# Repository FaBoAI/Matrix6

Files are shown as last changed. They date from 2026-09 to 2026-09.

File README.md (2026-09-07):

# Matrix Six

ESP32-S3-WROOM-1-N8R8を使った、Matrix5シールド向けのKiCad 10開発基板です。現行設計は **v0.8（2層・四隅R2 mm）**。内層配線を表裏へ移し、USBとGNDを再設計しました。オートルーターは使わず、部品配置と配線を個別に指定しています。

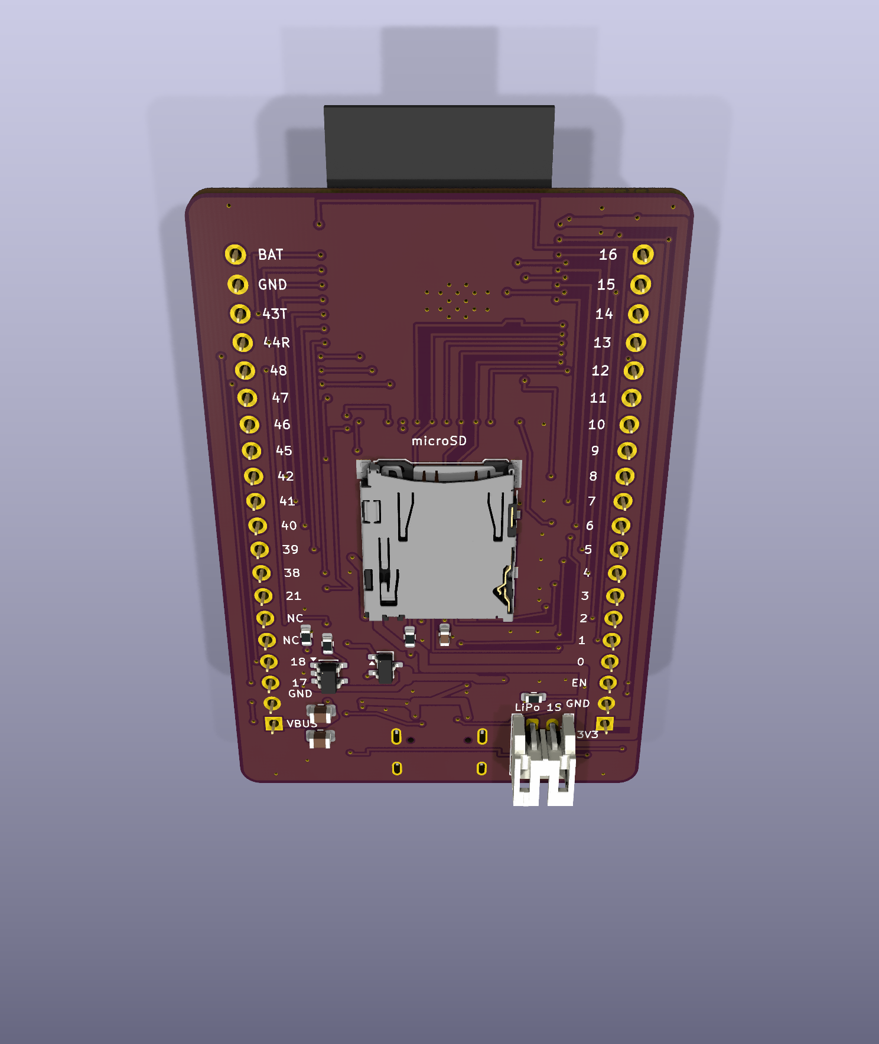
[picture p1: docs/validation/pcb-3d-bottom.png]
Matrix Six裏面3D・30度


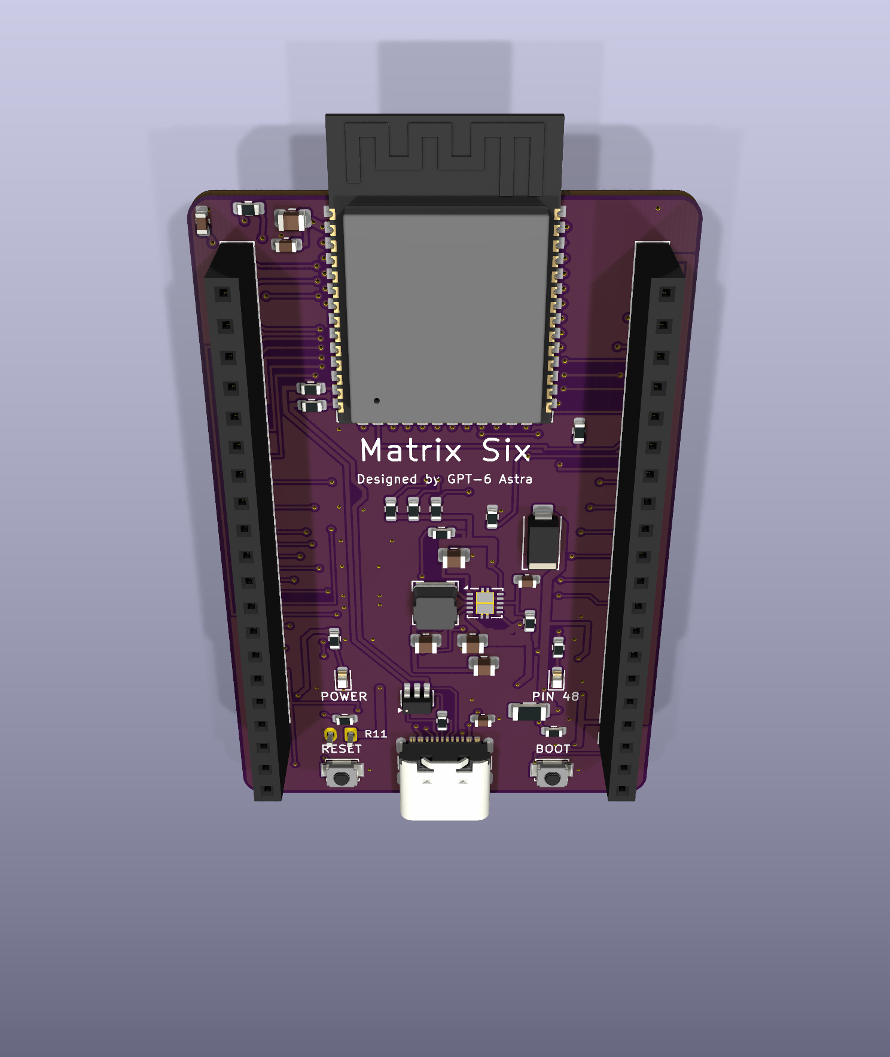
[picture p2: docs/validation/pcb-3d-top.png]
Matrix Six表面3D・30度


## KiCadで開く

[Matrix6.kicad_pro](hardware/Matrix6/Matrix6.kicad_pro)をKiCad 10で開いてください。KiCad標準のシンボル・フットプリント・3Dモデルライブラリをインストールし、同じフォルダーの `DevBoard.pretty` と `fp-lib-table` を一緒に保管します。動作確認版はKiCad 10.0.6です。

- ESP32-S3-WROOM-1-N8R8、ネイティブUSB-C、TPS63001によるUSB／LiPo両対応3.3 V電源。
- 裏面microSD（CS=10、MOSI=11、CLK=12、MISO=13）。口はアンテナ側へ向け、15.8 × 22.5 mmの抜き差し空間を確保。
- 裏面JST-PH 2ピンLiPo端子、MCP73831で公称100 mA充電、AO3401AによるUSB／電池自動切替。
- USBの左にRESET、右にBOOT。基板下部の赤LEDは `POWER`、青LEDはGPIO48の `PIN 48`。
- 40.64 × 61.00 mm、四隅R2 mm、2層FR4・公称1.6 mm・両面1 oz。USBは表面のみ・ビア0。表面のUSB両脇にGNDを確保し、表裏のGNDベタをビアで接続。
- H1/H2は各20ピン、ピッチ2.54 mm、列間33.02 mmのメスソケット。1番ピンはUSB側。
- 表面中央に大きな `Matrix Six`（文字高2.0 mm）、その直下に `Designed by GPT-6 Astra`（0.8 mm）。

## Matrix5シールドとの互換性

[Matrix5](https://github.com/FaBoAI/Matrix5)のMainとS1〜S11の実設計から端子情報を読み取り、全40位置と各シールドの使用信号を照合しました。**38端子の割り当てを合わせ、H2.20はVBAT**です。H2.5 / H2.6はNC（Matrix5のUSB D− / D＋）で、確認した11シールドはいずれも使用していません。

[端子表・シールド別照合・取り付け条件](docs/matrix5-compatibility.md)を参照してください。XY位置と使用ピンは一致していますが、積層高さ、アンテナ周辺、通電動作は実機での確認が必要です。USB-UART機能は追加していません。SDはシールドのSPI/I2C用GPIO11〜13を共有するため、競合する使い方ではカードを抜いてください。

電源計算の条件は周囲50℃、**3.3 V合計500 mA（MCU・SDを含む）＋VBUSシールド負荷100 mA＋充電100 mA**です。H1.1/H2.1は出力専用で、H2.1へ外部給電するとUSBへ逆給電できます。大電流のLED全点灯・コイル・ヒーターはこの条件に含みません。GPIOは3.3 Vで、S1用5 Vレベル変換はありません。

LiPoは保護回路付き1セル3.7 V／満充電4.2 V、500 mAh以上・放電定格1 A以上を基準とします。J3は**1番BAT+、2番GND**。同じJST形状でも電池側の極性を確認してください。電池動作中のH2.1に5 Vは出ません。セル温度センサーは搭載していません。

## 検証と図面

| 項目 | 保存したv0.8の結果 |
|---|---|
| DRC / ERC / 未配線 / 回路図整合性 | すべて0件 |
| 外形 | 四隅R2 mm、直線4本＋円弧4本で閉じた輪郭 |
| SD抜き差し空間 | 裏面15.8 × 22.5 mm、部品の配置禁止領域。重なり0 |
| Matrix5端子照合 | 全11シールドの使用ピン・40位置が一致 |
| USB | 表面のみ・ビア0、A/B両側とも幾何学的な長さ差0.01 mm未満 |
| USB本体下 | 表面配線・ビア・ベタ0。禁止領域の負の試験でも検出を確認 |
| USB直線部の表面GND | 両脇の幅0.5 mmを各1,563点検査、欠損0 |
| 電源降下の計算 | 3.3 V・500 mAでモジュールまで49.9 mV、H1まで27.9 mV |
| GND帰路のDC計算 | モジュール帰路500 mAで2.34 mV、入力帰路800 mAで6.45 mV |
| 最小ドリル | 0.3 mm。U1放熱穴はパッド0.8 mm、環状幅0.25 mm |

- [回路図](docs/validation/schematic.png) / [表面配線](docs/validation/pcb-top.png) / [裏面配線](docs/validation/pcb-bottom.png) / [SD抜き差し図](docs/validation/sd-access.svg)
- [DRC](docs/validation/drc.json) / [ERC](docs/validation/erc.json) / [シールド照合](docs/validation/matrix5-compatibility.json)
- [USB禁止領域](docs/validation/usb-keepout-validation.json) / [配線・電源計算](docs/validation/electrical-audit.json) / [GND計算](docs/validation/ground-plane-dc.json)
- [2層化の設計・検証範囲](docs/matrix-six-v08.md) / [USB断面計算](docs/analysis/two-layer-usb.json) / [表面GND検査](docs/validation/two-layer-ground.json)
- [検証対象CADのSHA-256](docs/validation/cad-sha256.json) / [回路図と30°3Dの並列表示](docs/validation/schematic-and-3d.png)

USBの均一断面は幅0.38 mm・線間0.18 mm・表面GNDとの間隔0.20 mm。FR4のεr=4.5を仮定した2D計算は約90.3 Ωです。裏面GNDは信号配線で4領域に分かれ、表面とビアで接続されており、連続した裏面参照プレーンではありません。USBの主な帰路は表面の両脇GNDとして設計しています。A側の長さにはR11のパッド間1.65 mmを含みます。

JLCPCB標準2層での管理インピーダンス保証は前提にしていません。断面・DC・配線温度の結果は設計計算であり、局所的な曲がりや長さ調整、コネクタを含むUSBの実測保証ではありません。試作機でUSB両挿し向き、SI/EMC、SD同時動作、給電切替・負荷・温度を確認します。

## JLCPCBへの試作発注

[v0.8の2層版製造データ](manufacturing/v0.8/README.md)を使用してください。48部品・26 BOMグループの型番は継承していますが、部品移動と表裏変更があるため **CPLもv0.8へ差し替えが必要**です。U1/U2等の放熱・パッド内ビアには充填と銅キャップを要求しており、両面実装費も残ります。最終削減額は新しい見積もりで確認してください。

既存のv0.7注文は4層版のデータです。v0.8の製造データとの混用はできません。部品在庫、実装位置・極性、CAMの確認が必要で、この作業では支払い・製造承認は行っていません。

JLCPCBに見積時点のGerberをアップロードし、基板5枚のWeb表示額は **$83.27**（部品・実装・送料別）でした。旧4層注文の$120.47から約31%減ですが、条件を最適化した4層比較額$86.68との差は約4%です。[見積もり内訳と条件](docs/analysis/two-layer-v08-quote.md)

## 検証の再実行

```sh
python3 scripts/verify_project.py
```

リポジトリをgit cloneして実行してください。設計ルール・互換性・外形の比較にはgit履歴が必要です。KiCad CLIと `pcbnew` / `wx` を使えるPythonが必要です。macOSの標準KiCadインストールは自動選択します。他の環境では `KICAD_CLI` と `KICAD_PYTHON` を指定してください。`ANALYSIS_PYTHON` にNumPy / SciPy / Shapely / Matplotlibを導入したPythonを指定すると、表裏を接続したGNDのDC計算も再実行します。検証はゾーンを再充填してPCBを保存し、レポートを更新するため、GUI上の編集を先に保存してください。

`scripts/manual_matrix5_layout.py` は初期インポートのコミットを入力とした、座標指定による移行記録です。オートルーターではありません。再実行すると後からのCAD編集を上書きするので、通常の検証には使いません。

v0.6の回路選定・電源条件は [設計メモ](docs/matrix-six-v06.md) に記録しています。

v0.7の外形変更は `scripts/round_board_corners.py`、v0.8の2層化は `scripts/redesign_two_layer.py` と `scripts/two_layer_routes.py` に記録しています。後者は `f12c10f` の4層CADから座標指定の変更を再生し、現在のCADを上書きするため通常の検証には使いません。v0.8の [外形検証](docs/validation/rounded-corners.json) はR2輪郭の保持と0.3 mm最小穴を確認します。版別の製造出力はPCBのリビジョンから出力先を決定します。

旧DevBoardの資料は [docs/devboard-v04](docs/devboard-v04/README.md) に履歴として保存しています。現在の端子・給電条件はこのREADMEとv0.6の互換性資料を使用してください。ライブラリの帰属は [THIRD_PARTY_NOTICES.md](THIRD_PARTY_NOTICES.md) に記載しています。

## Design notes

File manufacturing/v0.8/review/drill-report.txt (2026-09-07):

Drill report for Matrix6.kicad_pcb
Created on 2026-09-08T08:52:20

Copper Layer Stackup:
    =============================================================
    L1 :  F.Cu                      front
    L2 :  B.Cu                      back

Drill file 'Matrix6-PTH.drl' contains
    plated through holes:
    =============================================================
    T1  0.300mm  0.0118"  (166 holes))
    T2  0.300mm  0.0118"  (12 holes))
    T3  0.600mm  0.0236"  (4 holes)  (with 4 slots)
    T4  0.750mm  0.0295"  (2 holes))
    T5  1.000mm  0.0394"  (40 holes))

    Total plated holes count 224

Drill file 'Matrix6-NPTH.drl' contains
    unplated through holes:
    =============================================================
    T1  0.650mm  0.0256"  (2 holes))

    Total unplated holes count 2

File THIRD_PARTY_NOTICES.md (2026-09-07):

# Third-party library data

The KiCad community provides the standard symbols, footprints and 3D model references used by this project. See the [KiCad library license](https://gitlab.com/kicad/libraries/kicad-footprints/-/blob/master/LICENSE.md): CC BY-SA 4.0 with the KiCad electronic-design exception.

The project-local footprint collection in `hardware/Matrix6/DevBoard.pretty` contains modified KiCad library footprints and is distributed under that same library license. A copy of the upstream notice is included as `DevBoard.pretty/LICENSE.md`.

- `ESP32-S3-WROOM-1_Edge` derives from `RF_Module:ESP32-S3-WROOM-1`. The project changes the antenna/board-edge accommodation; standard module pad positions are retained.
- `USB4105_NoUnderbodyCopper` derives from `Connector_USB:USB_C_Receptacle_GCT_USB4105-xx-A_16P_TopMnt_Horizontal`. The project adds the named F.Cu track/via/pour keepout for the connector body; standard connector pad positions are retained.

Matrix5 interface references are derived from the owner's MatrixFive designs and the public [FaBoAI/Matrix5](https://github.com/FaBoAI/Matrix5) project. The raw private EasyEDA project was not included in this repository.

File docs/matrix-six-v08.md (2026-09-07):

# Matrix Six v0.8 — 2層への再設計

2026-09-08。v0.7の4層基板を、F.Cu / B.Cuだけの2層へ再設計した試作版です。内層配線を削除するだけの変換ではなく、信号・電源・USB・GNDを配線し直しました。オートルーターは使用していません。

## 維持した仕様

40.64 × 61 mm・四隅R2 mm、H1/H2の全40位置、Matrix5の38割当端子＋2 NC、全11シールドの使用ピンを維持しています。USBと左右のRESET/BOOT、下部POWER/PIN 48 LED、裏面microSDの15.8 × 22.5 mm抜き差し空間、裏面LiPo端子と100 mA充電・自動切替を維持しました。表面のMatrix Sixは文字高2.0 mmへ拡大し、直下にDesigned by GPT-6 Astra（文字高0.8 mm）を配置しています。両行は基板中心X=117.78 mmに揃え、R8をモジュール右側（X=129.3、Y=120.3 mm、90°）へ移動して文字領域を空けました。IO46の分岐配線を引き直し、GND側は表面ベタに直接接続しています。

部品は48個、BOMは26グループで同じ型番です。配線経路のためR5/C4/C5/R8/R9等を移動し、R6を裏面、C11を表面へ移しました。C11はmicroSD用のバルク容量で、裏面スロット近傍のC12 100 nFは保持しています。現在の座標・面・回転は[v0.8 CPL](../manufacturing/v0.8/assembly/Matrix6-v0.8-CPL.csv)と[実装基準図](../manufacturing/v0.8/review/Matrix6-assembly-reference.png)を正としてください。

## 層構成と穴

| 項目 | v0.8 |
|---|---|
| 銅層 | F.Cu / B.Cuのみ |
| 製造時の指定 | FR4、公称1.6 mm、両面1 oz |
| CAD断面 | 表裏銅箔各0.035 mm、コア1.530 mm、εr=4.5 |
| レジストのモデル | 各0.0127 mm、εr=3.8。CAD全厚はレジスト込み1.6254 mm |
| 通常ビア | 完成穴径0.30 mm、銅箔径0.60 mm |
| U1放熱穴12個 | 完成穴径0.30 mm、銅箔径0.80 mm、環状幅0.25 mm |
| 最小PTH環状幅 | USBの長穴部0.20 mm、検査下限0.18 mm |

U1の旧0.2 mm穴を0.3 mmへ広げ、2層の微細穴料金区分を避ける形状にしました。放熱・パッド内ビアのエポキシ充填と銅キャップは製造要求に残ります。コネクタ挿入穴、USB長穴、NPTHは開口します。充填方式・料金・仕上がりの最終確認はCAMが必要です。

## USBとGND

USBはすべて表面、ビア0。USB本体下の表面配線・ビア・ベタは0です。禁止領域に意図的な違反を置いた一時コピーでも検出を確認しました。

均一断面は **線幅0.38 mm、線間0.18 mm、両脇GNDとの間隔0.20 mm**。直線区間Y=128.5〜141.5 mmで、各側0.5 mm幅のGND帯を各1,563点検査し、欠損0を確認しました。裏面ベタは信号配線で4領域に分かれ、表面とスティッチを通じて導通しています。裏面全体を連続した参照プレーンとは見なしません。

| USB経路 | D− | D＋ | 長さ差 |
|---|---:|---:|---:|
| 直列抵抗〜USB-C A側 | 48.020 mm | 48.020 mm | <0.01 mm |
| 直列抵抗〜USB-C B側 | 46.303 mm | 46.303 mm | <0.01 mm |
| モジュール〜直列抵抗 | 1.714 mm | 1.712 mm | 0.003 mm |

A側D＋にはR11のパッド中心間1.65 mmを幾何学的な長さとして含みます。部品内部の電気的遅延を測定した値ではありません。

[2D奇モード静電界計算](analysis/two-layer-usb.json)では、公称90.22 Ω、細かいメッシュで90.26 Ω。両脇GND幅を検査済みの0.5 mmに限定して90.26 Ω、遠方の裏面参照を除いた場合90.30 Ωでした。線幅±0.02 mm、線間±0.02 mm、GND間隔±0.02 mm、εr±0.2を組み合わせた感度ケースは83.72〜96.91 Ωです。**これらの振れ幅は仮定で、JLCPCBの保証公差ではありません。**

この計算は均一断面に限定され、コネクタ・部品・曲がり・長さ調整部や周波数依存損失を含みません。管理インピーダンス保証、TDR、USB規格適合の代わりにはなりません。JLCPCB標準2層では管理インピーダンスの保証を前提にせず、試作での確認を必要とする設計です。[EspressifのUSB配線要件](https://docs.espressif.com/projects/esp-hardware-design-guidelines/en/latest/esp32s3/pcb-layout-design.html)、[JLCPCBの材料・製造能力](https://jlcpcb.com/capabilities/pcb-capabilities/)

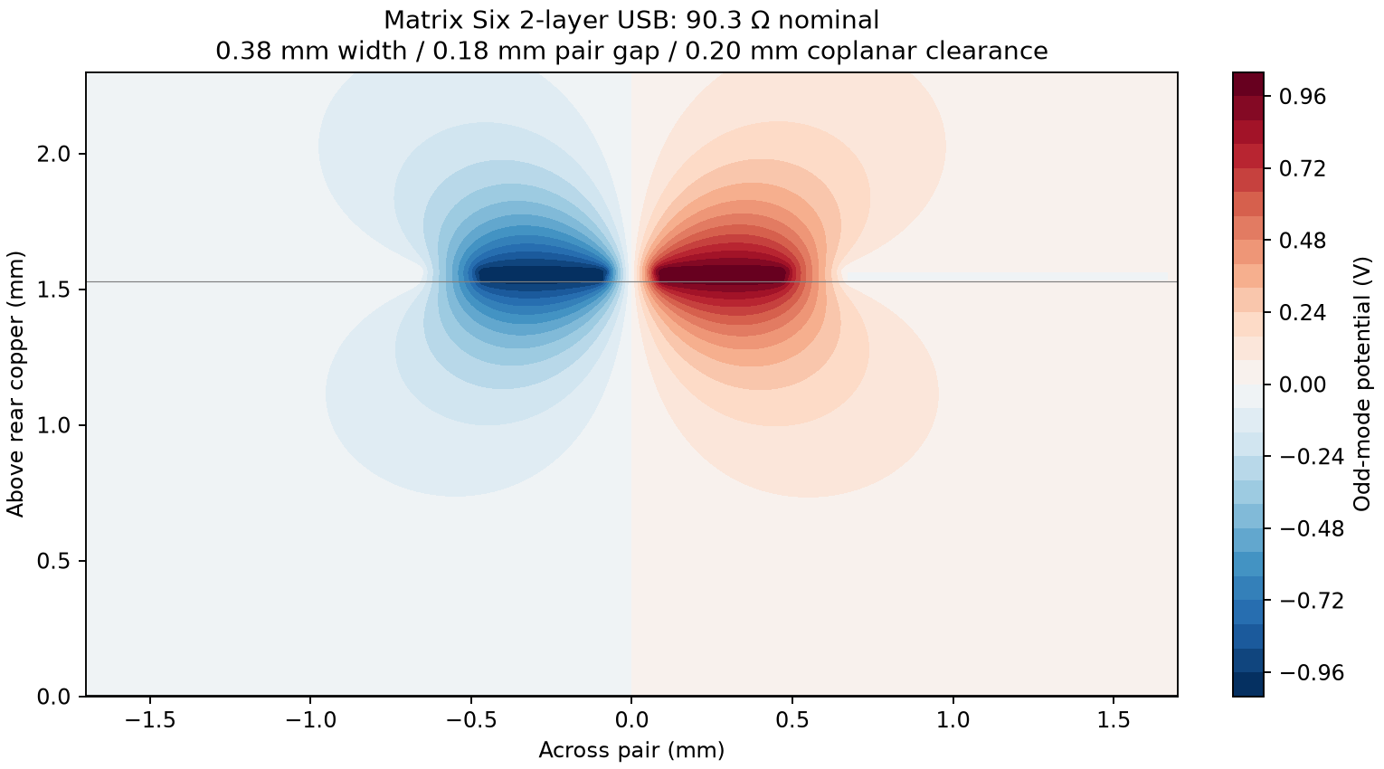
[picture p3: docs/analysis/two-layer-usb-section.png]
USB断面モデル


## 電源・帰路の計算

銅温度60℃、銅厚35 µm、ビアめっき20 µmの仮定です。配線の抵抗は実際の経路から算出しています。負荷条件と電源ICの制限は[README](../README.md)および[v0.6電源設計](matrix-six-v06.md)に従います。

| 経路 | 負荷 | 銅配線の電圧降下 |
|---|---:|---:|
| 3.3 Vコンバーター→ESP32 | 500 mA | 49.9 mV |
| 3.3 Vコンバーター→H1 | 500 mA | 27.9 mV |
| 3.3 Vコンバーター→microSD | 200 mA | 11.0 mV |
| LiPo→切替PFET | 800 mA | 13.2 mV |
| 切替PFET→コンバーター | 800 mA | 12.7 mV |

各行は経路の検討条件で、これらの電流を同時に加算してよい意味ではありません。3.3 VはMCU・SD・シールドを含む合計500 mAを設計条件とします。

表裏の充填済みGND、GNDパッド・配線、穴、64個の層間接続を含めた[DCメッシュ計算](validation/ground-plane-dc.json)では、モジュール帰路500 mAで2.34 mV、入力帰路800 mAで6.45 mVです。前者は0.125→0.0625 mmのメッシュ細分化で1%以内に収束しました。表面GND検査の44個という値は通常のGNDビア数で、DCモデルの64接続はGNDのPTHパッド等も含みます。接触抵抗・はんだ抵抗は含みません。

IPC-2221式による配線温度上昇のスクリーニング値は最大約6.1℃。周囲・銅温度の仮定、熱の拡散、部品自身の損失によって実温度は変わります。IPC-2152評価や熱解析・実測ではありません。

## 検証と製造の状態

- KiCad 10.0.6：全重大度のDRC 0、ERC 0、未配線0、回路図整合性違反0。
- Matrix5の40位置と11シールド、SD抜き差し、USB底面禁止領域、R2外形、最小穴・環状幅を検証。
- GND再充填後の[CADハッシュ](validation/cad-sha256.json)を保存。製造出力時に同一CADか再照合。
- USB両挿し向き・実機通信、SI/EMC、Wi-FiとSDの同時動作、低電池時の電源切替、突入電流・最大負荷・温度は試作で検証する項目。
- v0.7の既存注文は旧4層のまま。v0.8で支払い・製造承認は行っていない。最終的な削減額は2層の再見積もりで確定する。

再現用の座標指定変更は `scripts/redesign_two_layer.py` と `scripts/two_layer_routes.py`。4層版 `f12c10f` を入力として現在のCADを上書きするので、通常は `scripts/verify_project.py` だけを実行してください。

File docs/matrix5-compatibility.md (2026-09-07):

# Matrix5シールド互換性 — Matrix Six v0.6

Matrix5 MainのJ4/J5と同じ順序で、Matrix6のH1/H2を配線しました。ピッチ2.54 mm、各20ピン、列間33.02 mmです。表面から見てH1が左、H2が右、**1番ピンはUSB側**です。旧DevBoard v0.4の30.48 mmヘッダーとは互換ではありません。

照合元は、2026-09-07に読み取り専用APIで取得したEasyEDAの `MatrixFive_Main_PCB` とS1〜S11の実設計です。公開されている製造ZIPの `FlyingProbeTesting.json` でも位置・使用ピンを照合しました。公開側の基準コミットは [Matrix5 4e5bad0](https://github.com/FaBoAI/Matrix5/tree/4e5bad09b81449c644275b11321cdfa5019caf93) です。抽出した[Mainの端子表](reference/matrix5-pinout.json)と[シールドの使用端子](reference/matrix5-shield-interface.json)を保存しています。

## 端子表

| ピン | H1 | H2 |
|---:|---|---|
| 1 | 3V3出力 | VBUS出力（F1保護後） |
| 2 | GND | GND |
| 3 | EN | GPIO17 |
| 4 | GPIO0 / BOOT | GPIO18 |
| 5 | GPIO1 | NC：Matrix5ではUSB D− |
| 6 | GPIO2 | NC：Matrix5ではUSB D＋ |
| 7 | GPIO3 | GPIO21 / S1 DATA |
| 8 | GPIO4 | GPIO38 |
| 9 | GPIO5 | GPIO39 |
| 10 | GPIO6 | GPIO40 |
| 11 | GPIO7 | GPIO41 |
| 12 | GPIO8 | GPIO42 |
| 13 | GPIO9 | GPIO45 |
| 14 | GPIO10 | GPIO46 |
| 15 | GPIO11 / MOSI / SDA | GPIO47 |
| 16 | GPIO12 / SCLK / SCL | GPIO48 / 青LED |
| 17 | GPIO13 / MISO | GPIO44 / RX |
| 18 | GPIO14 / HEAT_EN | GPIO43 / TX |
| 19 | GPIO15 | GND |
| 20 | GPIO16 | VBAT（J3の電池端子） |

**38端子の信号・電源を合わせ、USB D±の2端子は意図的に未接続です。** H2.20をVBATへ接続しました。確認した11シールドの使用端子は一致しています。SDはGPIO10〜13を共有します。GPIO11/12をI2Cとして使うときなど、カードと競合する構成ではカードを抜いてください。

## シールド別の照合範囲

| シールド | 照合した機能 | 使用端子数 |
|---|---|---:|
| S1 WS2812 6×6 | H2.7のGPIO21、VBUS、GND | 5 |
| S2 ICM20948 | GPIO1〜9のCS、SPI、3V3、GND | 16 |
| S3 BME690 | GPIO1〜9のCS、SPI、3V3、GND | 16 |
| S4 MLX90393 | GPIO1〜9のCS、SPI、3V3、GND | 16 |
| S5 VL53L1X | GPIO1〜9のXSHUT、I2C、3V3、GND | 15 |
| S6 BMP581 | GPIO1〜9のCS、SPI、3V3、GND | 16 |
| S7 VL6180X | GPIO1〜9のCE、I2C、3V3、GND | 15 |
| S8 Touch | GPIO1〜9 | 9 |
| S9 MagPix | GPIO1〜9、VBUS、GND | 13 |
| S10 AirFlow | GPIO1〜9、GPIO14、3V3、VBUS、GND | 15 |
| S11 Display | GPIO1〜4、MOSI/SCLK、3V3、VBUS、GND | 11 |

各シールド40か所のパッド座標と上表の使用端子を、保存したKiCad PCBに対して検査しています。[検証結果](validation/matrix5-compatibility.json)はピン配置の一致を示すもので、実物を積層して通電した結果ではありません。S2/S4/S6/S9はMatrix5側の改版履歴にも従ってください。

## 機械寸法と取り付け

Matrix6は40.64 × 61.00 mm。H1.1=(101.27,153.26)、H2.1=(134.29,153.26) mmで、番号が増える方向はKiCad上で−Yです。標準シールド40.64 × 53.34 mmを重ねると、外形はX=97.46〜138.10、Y=102.46〜155.80 mmとなります。USBとRESET/BOOTはその下側に残ります。S11は長い基板のため、外形全体はこの範囲を超えます。

H1/H2は表面の1×20メスソケット用フットプリントです。ソケット・オスピン・スペーサーの組合せは、シールド裏面の部品とMatrix6のESP32モジュール等の高さを実測して決めてください。ヘッダーのXY一致だけで積層高さや筐体への適合は保証できません。アンテナ上を金属や別基板で覆わず、積層した状態の無線性能も確認します。

## 電源・ファームウェアの条件

- I/Oは3.3 V。S1へ出すGPIO21も3.3 Vで、追加の5 Vレベル変換はありません。S1実装LEDの入力閾値と波形を試作で確認してください。
- 3V3の計算条件はMCU・SDと外部負荷の**合計500 mA**。これにVBUSシールド負荷**100 mA**とLiPo充電100 mAを追加した場合を計算しました。VBUSはF1の後、D1の前から供給します。
- 電池時はH2.1の5 V出力を供給しません。J3は1番BAT+・2番GND、保護付き1S 3.7 V／4.2 V LiPo用です。
- H1.1/H2.1は出力です。H2.1へ外部電源を直接接続するとUSB側へ逆給電できます。F1は逆流防止素子ではありません。
- S1の全点灯、S9の複数コイル駆動、S10のヒーター等は上記電源条件で保証していません。外部電源を使うシールドは、そのシールドの電源切替・逆流防止設計に従います。
- GPIO0/3/45/46は起動条件に関係するため、リセット中のシールド側の負荷・プル抵抗を確認します。青LEDはGPIO48です。
- Matrix5のSPI/I2C/CS/DATA番号はそのまま使えます。シールドに対応するファームウェアを選び、給電を切ってから交換してください。ファームウェアの移植・実機動作試験はこのコミットには含みません。

## 電気的な検証

[DRC](validation/drc.json)、[ERC](validation/erc.json)、未配線、回路図整合性はすべて0件。オートルーターは使わず、個別の配線座標を指定しました。USBの銅配線はv0.4と同一、表面のみ・ビア0、A側の幾何長合わせにはR11の1.65 mmパッド間距離を含みます。

L2は連続したGND 1領域、USB直下13,182点の欠損0。USB本体下の表面配線・ビア・ベタは0で、禁止領域に試験用配線を入れた一時コピーでは2件の禁止違反を検出しました。[USB禁止領域の検証](validation/usb-keepout-validation.json)

3.3 V配線の電圧降下は500 mAでモジュールまで53.5 mV、H1まで31.4 mV。L2の戻り経路は新しいU2のGNDビアへ再計算しました。周囲50℃・効率80%などの仮定による計算であり、実測値ではありません。層構成はJLC04161H-7628相当の4層、USB均一断面の既存2D推定は約91.1 Ω。製造者のインピーダンス承認、TDR、電源負荷・温度・実効容量、積層状態の動作は試作で確認します。[電源・配線計算](validation/electrical-audit.json)、[GND計算](validation/ground-plane-dc.json)

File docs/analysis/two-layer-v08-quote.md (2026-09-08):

# v0.8 2層版のJLCPCB基板見積もり

> この見積もりはR8移動・文字の中央寄せより前の記録です。更新版は再アップロード済みで、最新状況は[発注準備の記録](two-layer-v08-order.md)を参照してください。

2026-09-08、拡大したMatrix Sixと直下のDesigned by GPT-6 Astraを含む見積時点のv0.8 Gerber ZIPをアップロードしました。JLCPCBは **2層、40.64 × 61 mm** と認識し、ファイルをProjects > Quotesへ保存した旨を表示しています。

比較条件は基板5枚、Standard PCBA・両面実装2枚、JLC追加レール込み70.64 × 71 mm。公称1.6 mm、紫、白シルク、S1000H TG155、ENIG 1u、両面1 oz、エポキシ充填・銅キャップ、Horizontal Electroless Copper Plating、0.3 mm穴料金区分、フライングプローブ全数導通検査、製造図面確認ありです。製造図面は自動承認しない設定を選びました。

| 基板費の内訳 | 2層v0.8 |
|---|---:|
| Special Offer | $4.00 |
| ビア充填・キャップ | $50.49 |
| ENIG | $17.00 |
| 材料指定 | $7.39 |
| ビアめっき方法 | $3.35 |
| 製造図面確認 | $1.04 |
| **基板5枚のWeb表示額** | **$83.27** |

JLCONE用の表示は$81.27でした。表はWebの金額で、部品・実装・送料・決済手数料等を含みません。Standard PCBAの部品費・実装費は未算出（画面は「-」）です。今回はGerberと基板費を確認した段階で、新BOM/CPLのアップロード・実装位置照合・在庫確認は未実施です。

前回の4層注文の基板費$120.47との差は **$37.20（約31%）**。ただし、[4層の製造条件を最適化した比較](two-layer-cost-review.md)の$86.68に対しては **$3.41（約4%）** の削減に留まります。2層では充填・キャップ料金が高く、単に層数を減らした効果の多くを相殺しています。これは2層への再設計後に確認した料金であり、総額の大幅削減を保証する結果ではありません。

現行v0.8には放熱・パッド内ビアが残るため、料金だけを目的に充填を外すことはしません。さらに削減する場合は、ビア・放熱パッド・ペースト開口を含む別の実装性検討が必要です。

元のv0.7注文はこの作業で変更していません。新規の注文確定・支払い・製造承認は行っていません。管理インピーダンス保証のない2層試作版として、実機USB・電源・熱試験とCAM確認が必要です。

出典：[JLCPCB見積画面](https://cart.jlcpcb.com/quote)、[v0.8製造パッケージ](../../manufacturing/v0.8/README.md)。価格は確認時点の表示で、製造審査や数量・条件変更により変わります。

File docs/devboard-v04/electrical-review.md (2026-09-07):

# v0.4 電気設計レビュー

> 履歴資料：以下は移行前のv0.4の記録です。現在のヘッダー配置・給電条件・検証値は [Matrix6 v0.5の互換性資料](../matrix5-compatibility.md) を参照してください。旧5 Vヘッダー入力の説明は現行H2.1には適用できません。

対象：`ESP32-S3-DevBoard.kicad_pcb / .kicad_sch / .kicad_pro / .kicad_dru`。2026-09-07、KiCad 10.0.6。

追記：表面中央に `Designed By GPT-6 Astra` を追加しました。文字以外の基板データが前版と完全一致することを構文比較で確認し、DRC・未配線・回路図整合性を再確認しました（いずれも0件）。`review/design-credit-validation.json` に変更前後のハッシュと比較結果を記録しています。以下のUSB禁止領域試験は文字追加前の基板で実施した記録で、配線・部品・禁止領域は変わっていません。

## 1. 修正内容と判定範囲

USBコネクタ本体下の配線退避、禁止領域の登録、USBの長さ合わせ、4層スタックアップ、専用GND層、電源配線の拡幅、熱損失の大きいLDOから降圧回路への変更を実施しました。設定した設計条件について、保存されたPCBの配線形状・接続・層構成を再検証しています。オートルーターは使用していません。

DRC合格と、実測によるUSB／熱設計の認定は別の確認です。本レビューは試作前の設計計算です。量産承認・製造業者によるインピーダンス保証・実測温度を表すものではありません。

設計条件：3.3 V側の合計負荷500 mA連続、周囲50℃、USBコネクタにおける負荷時電圧4.75～5.25 V。3V3ヘッダは出力専用、5Vヘッダ入力は安定化5 Vのみです。USB入力側は550 mAで配線を評価しました。各ヘッダの500 mA計算は個別の評価ケースであり、同時に各500 mAを供給する定格ではありません。

## 2. USBの長さとインピーダンス

[EspressifのUSBレイアウト指針](https://docs.espressif.com/projects/esp-hardware-design-guidelines/en/latest/esp32s3/pcb-layout-design.html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)の90 Ω ±10%、等長、連続した基準GND、ビア削減を設計目標にしました。

| 経路：直列抵抗のUSB側パッドからUSB-C | D−中心線長 | D＋中心線長 | 長さ差 |
| --- | ---: | ---: | ---: |
| A7 / A6（R11の端子間寸法を含む） | 48.0197 mm | 48.0197 mm | <0.001 mm |
| B7 / B6 | 46.3031 mm | 46.3031 mm | <0.001 mm |
| モジュールから直列抵抗 | 1.7145 mm | 1.7116 mm | 0.0029 mm |

全USB配線はF.Cu、USBビアは0個です。許容差は0.10 mmで管理します。小数点以下の値はCAD上の中心線長で、製造精度や端子内部の電気長を表しません。USB-CのA/B重複接点への分岐も、それぞれ独立に確認しました。

v0.4ではA6側に実装必須の0ΩジャンパーR11を追加しました。B接点は通常DRCの `fromTo` で0.10 mmを検査し、A/Bの両経路を独立スクリプトで測定します。A6経路はネットがR11で分かれるため、連続ネット用DRCをそのまま流用しません。A側D＋の銅箔・パッド中心までの幾何長は46.3697 mm、R11のパッド中心間距離は1.6500 mm、合計48.0197 mmです。これはジャンパー内部の実測電気長ではありません。パッケージの遅延・寄生容量・不連続は実機評価に含めます。旧v0.3のA接点用DRCレポートはv0.4の根拠には使いません。

### USBコネクタ本体下の配線：退避と禁止領域の登録を完了

採用部品はGCT USB4105-GF-A-120です。[メーカー図面](https://gct.co/files/drawings/usb4105.pdf)のRev. B4（2023-12-18）1ページ目にある本体外形全体を使い、プロジェクト独自の保守的な禁止領域を登録しました。メーカーがこの範囲の配線を一律禁止していると主張するものではありません。

- J1のフットプリントを `DevBoard:USB4105_NoUnderbodyCopper` とし、F.Cuの配線・ビア・ベタを禁止。メーカー図面に対応するコネクタ自身のパッド・穴・外形寸法は維持しています。
- 禁止領域は基板座標x=113.310～122.250 mm、y=154.325～161.675 mmです。内層のGNDは維持しています。
- D＋の本体側0.605 mm折り返しを撤去。信号・電源・CCの表面配線はパッド内のy=154.000 mmで止め、コネクタ本体へ入りません。D＋配線の銅箔端から本体外形まで0.225 mmです。
- CC1ビアを(116.53,156.30)から(115.95,152.75)へ移動。表面配線と内層配線を引き直し、本体下を通るCC1経路を撤去しました。
- R11を(117.53,151.75)に追加し、コネクタ本体外でD＋のA6枝を交差させました。部品は[Vishay CRCW06030000Z0EA](https://www.vishay.com/docs/20035/dcrcwe3.pdf)、0603の0Ωジャンパーです。回路図・PCBのMPNを一致させています。R11を未実装にすると片向きのUSB通信が成立しません。
- U3を(115.10,149.00)へ移動し、周辺のVBUS/GND配線を整理しました。USBは全区間F.Cuで、USBビアは0個です。オートルーターは使っていません。

保存基板の本体下トラック・ビアは0件、表面ベタの内部サンプル6,497点中、銅箔ありは0点です。コネクタ自身の接続パッドは必要なので禁止対象から除き、内層GNDの連続性も別に検査しています。

さらに、**一時コピーだけ**に本体下の配線1本とビア1個を置く負の試験を行い、両方で `items_not_allowed` 違反が発生することを確認しました。試験用の違反は製品基板に保存していません。`review/usb-keepout-validation.json` が合否の記録、`review/usb-keepout-probe.json` は故意に違反を入れた一時コピーのDRC出力です。製品基板の `drc-final.json` は違反0です。

この退避により、問題となった本体下トラック／ビアをレジストの絶縁性能に依存させる状態は解消しました。通常のはんだ実装確認とUSB動作試験は別途実施します。

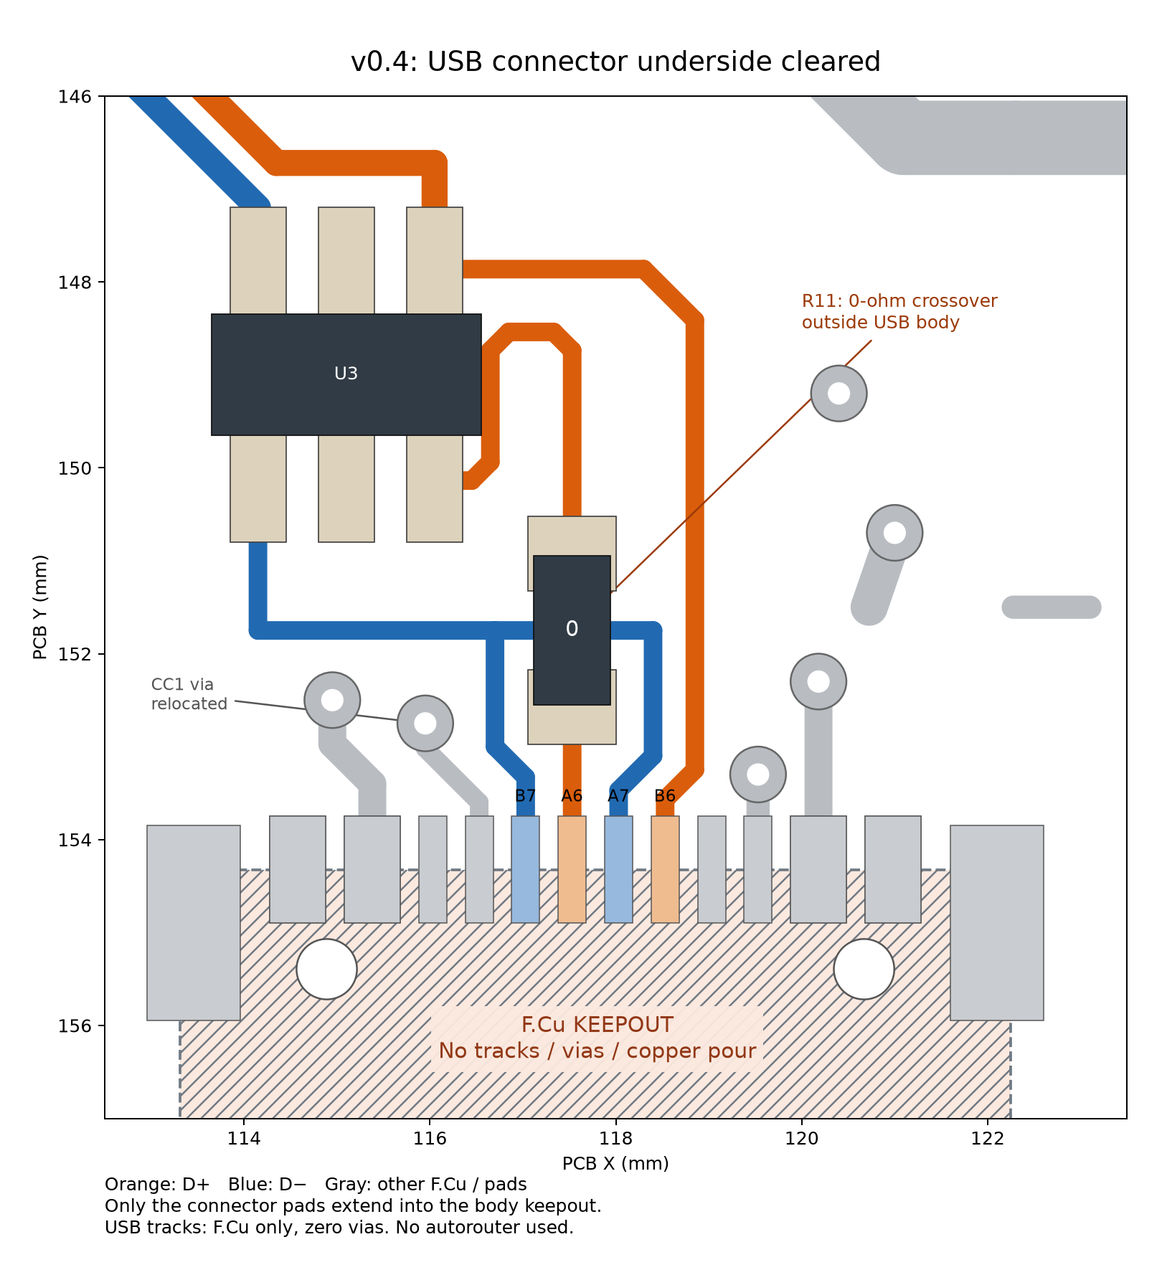
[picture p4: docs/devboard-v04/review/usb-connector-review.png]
USB端子下の配線修正


### 採用スタックアップ

[JLCPCBのスタックアップ／計算画面](https://jlcpcb.com/pcb-impedance-calculator)で確認した **JLC04161H-7628、4層、呼称1.6 mm、外層1 oz・内層0.5 oz** を設定しました。

| 層 | 厚さ | 用途・材料 |
| --- | ---: | --- |
| F.Cu | 0.0350 mm | 部品・USB・局所電源・GND |
| プリプレグ | 0.2104 mm | 7628 RC49%、計算εr=4.4 |
| In1.Cu / L2 | 0.0152 mm | 専用GND |
| コア | 1.0650 mm | FR4、設定εr=4.6 |
| In2.Cu / L3 | 0.0152 mm | 電源・GPIO |
| プリプレグ | 0.2104 mm | 7628 RC49%、計算εr=4.4 |
| B.Cu | 0.0350 mm | 電源主配線・GPIO・GND |

銅箔＋絶縁材の合計は1.5862 mm。KiCadには表裏各0.0127 mmのソルダーレジストを含む1.6116 mmを登録しました。製造指示上は上記の呼称1.6 mmスタックアップです。表面処理はENIG設定です。

均一区間の寸法は配線幅0.28 mm、ペア間のエッジ間隔0.20 mm、表面GNDとの間隔0.50 mm、基準面まで0.2104 mm、銅厚0.035 mmです。細ピッチの端子逃げは0.20 mmです。εr=4.4は[JLCPCBの材料特性](https://jlcpcb.com/capabilities/pcb-capabilitiesPLC)を参照し、レジストのεr=3.8、導体上厚0.0127 mm・基材上厚0.02032 mmは[同社の計算モデル](https://cart.jlcpcb.com/client/template/placeOrder/impedance.html)を用いました。

独立した2D準静電界計算で奇モード容量Cと真空時C₀を解き、`Zdiff = 2 / (c × √(C × C₀))` から算出しました。

| 計算 | 差動インピーダンス |
| --- | ---: |
| εr=4.4、最大格子5 µm | 90.889 Ω |
| εr=4.4、最大格子2.5 µm | **91.096 Ω** |
| εr=4.6、最大格子5 µm（材料感度） | 89.375 Ω |

格子細分化による差は0.207 Ω。90 Ωの目標範囲81～99 Ω内です。JLCPCBの画面は計算待ちのまま結果を返さなかったため、この数値は**JLCPCBが発行した計算値ではありません**。独立ソルバー・入力・結果を保存しています。

この計算が対象とするのは均一な断面です。コネクタ、ESD素子、抵抗パッド、曲がり、分岐の3D不連続、製造ばらつき、実機のアイパターンは含めていません。基板製造時にこのスタックアップを指定し、実際の誘電率・仕上がり銅厚に基づく製造業者の最終補正と90 Ω差動TDRクーポンを確認してください。

USB断面電位

## 3. GNDの連続性

In1.Cuから信号・電源トラックを移し、アンテナ領域を除いた専用GNDゾーン `L2_CONTINUOUS_GND` を設けました。全層のアンテナ禁止領域を保持しています。L2の信号トラックは0本、塗りつぶし銅箔は1つの連続領域です。銅箔面積は約1,933 mm²です。

USB全区間について、0.025 mm間隔で中心と両エッジ外側0.05 mmを検査しました。**13,182点中、L2 GND欠損0点**です。通常のビア・スルーホールのアンチパッドは存在しますが、USB直下を横切るプレーン分断はありません。

降圧回路の入力GNDを最短で閉じ、周辺にGNDビアを追加しました。モジュール下面の露出はんだパッド外側にも4つのGNDビアを配置し、はんだパッド内へのドリル追加を避けています。

実際のL2ポリゴンとアンチパッドを抵抗メッシュにして、モジュール側GNDビア(118.8,109.7)から降圧回路側GNDビア(119.3,141.3)へ500 mAを流した計算では、プレーン降下は約1.36 mVでした。0.25 mm格子では1.43 mV、0.125 mm格子では1.36 mVです。接点は直径0.6 mmの等電位領域とし、点電極の格子依存性を避けました。

表裏GNDの並列効果は計算に含めず、L2だけを評価しています。ビアバレル・表面GND内の局所拡散・はんだの抵抗はこの値に含みません。入力側の電圧予算にはGND戻りとして別途10 mVを確保しました。

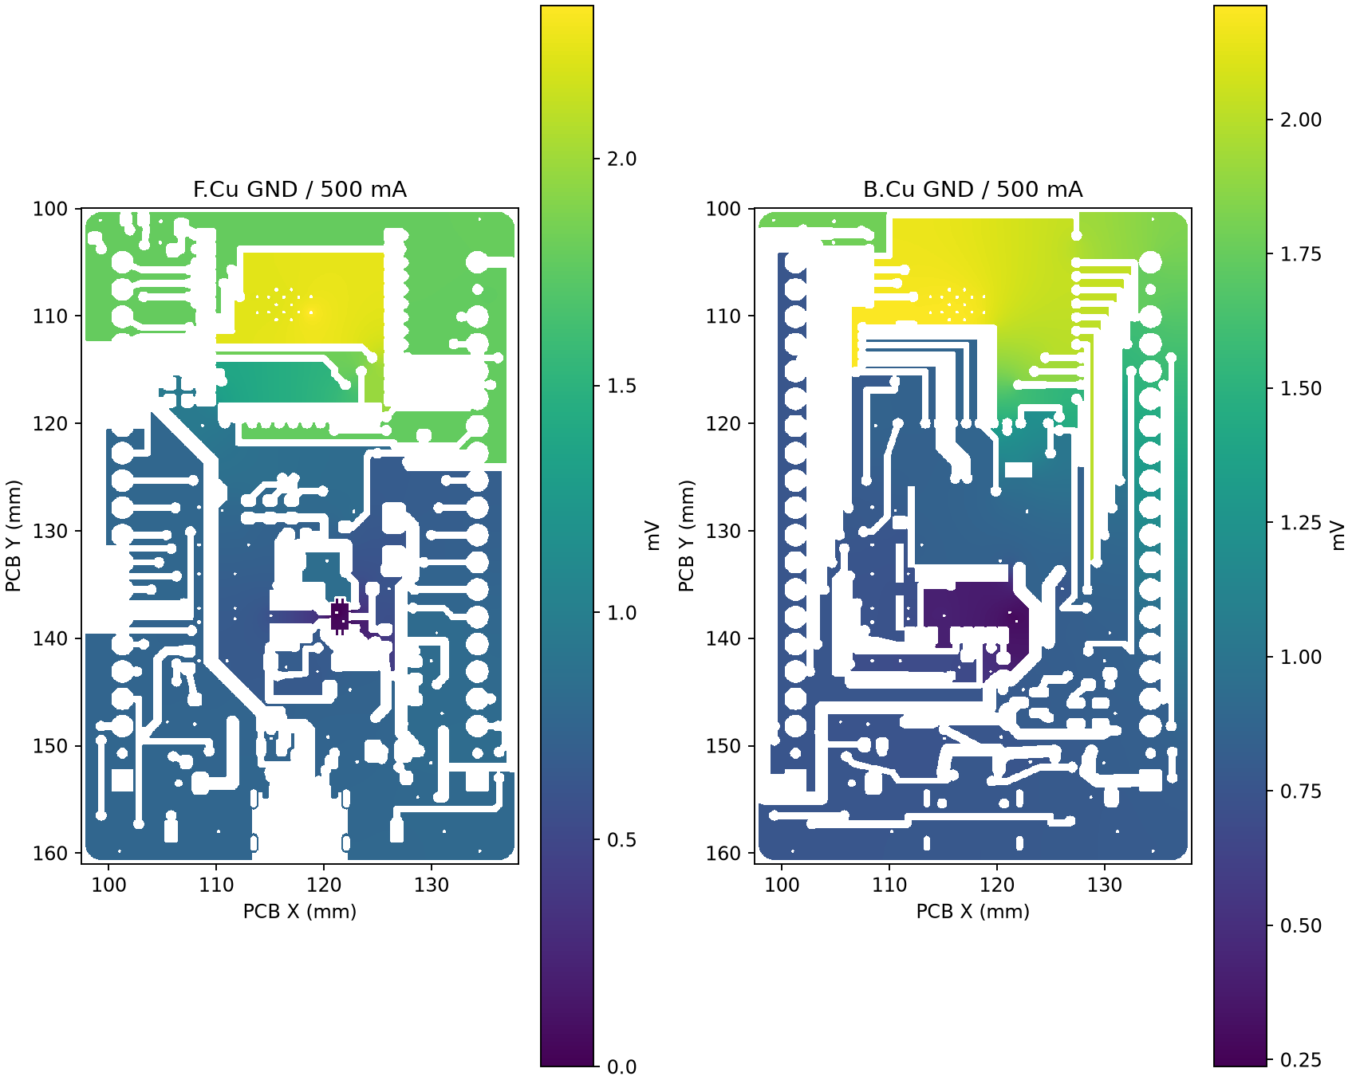
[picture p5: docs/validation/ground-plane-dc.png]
GNDプレーンのDC計算


## 4. 電源回路と電流容量

元のAP7361C LDOは入力5.25 V、出力約3.3 V、500 mAで約0.99 Wを消費し、周囲50℃・熱抵抗110℃/Wの計算で接合温度約159℃となるため、AP63203WU-7の3.3 V降圧回路へ変更しました。

U2のVINとC1、GNDのループを表面で短く接続し、SWからL1までの銅箔面積を小さくしました。FBは出力コンデンサから分岐し、SWから離して引いています。主配線は3.3 V外層0.8 mm、5 V内層1.0 mm、ヘッダ枝0.8 mmを基本とし、出力主経路のヘッダ間通過部のみ短い0.4 mmです。電源の主要な層間接続にはビアを2本ずつ設けています。

| 部品 | v0.4 |
| --- | --- |
| U2 | AP63203WU-7、TSOT-23-6、固定3.3 V |
| L1 | Bourns SRN4018-4R7M、4.7 µH |
| C1 | 22 µF / 16 V X5R、0805 |
| C2 + C8 | 22 µF / 10 V X5R ×2、0805 |
| C7 | 100 nF / 16 V X7R、0603、BST–SW間 |
| F1 | MF-NSMF110/16X-2、1.1 A hold、1206 |
| D1 | Vishay SS14-E3/61T、SMA |
| R11 | Vishay CRCW06030000Z0EA、0603、0Ω、USB A6枝の交差用 |

[AP63203データシート](https://www.diodes.com/datasheet/download/AP63200-AP63201-AP63203-AP63205.pdf)の固定出力接続と推奨容量を基にしています。L1は推奨範囲2.2～10 µH内で選びました。[SRN4018の定格](https://www.bourns.com/docs/product-datasheets/srn4018.pdf)はIrms=1.9 A、Isat=2.0 A、DCR最大84 mΩです。

Lの−20%公差、1.1 MHzの−6%拡散、入力5.25 Vを使うと、リップル電流0.315 A p-p、500 mA負荷時のピーク0.658 A、実効値0.508 Aです。インダクタの通常運転電流には余裕があり、巻線損失は銅温度60℃で約25 mW、定格温度上昇40℃を電流二乗で換算した粗い見積りは約2.9℃です。IsatはICのピーク電流制限より低いため、2 A運転や故障時の飽和余裕まで保証する設計にはしていません。

C1は使用電圧・温度・公差・経時変化を含む実効容量10 µF以上、C2+C8は合計22 µF以上を部品選定条件としています。名目容量だけでは判定できないため、具体的な採用品番のDCバイアス特性は部品確定時に照合します。入力コンデンサの必要リップル電流は0.25 A rms、出力容量22 µF・合成ESR10 mΩを仮定した定常リップル計算は約4.9 mV p-pです。実測の負荷過渡・制御安定性は別途確認が必要です。

### 銅箔の抵抗と温度上昇

銅の抵抗率は20℃で1.724×10⁻⁵ Ωmm、温度係数0.00393/℃、抵抗計算温度60℃。外層35 µm、内層15.2 µm、ビアのめっき厚20 µmを仮定しました。既存の1本の導通経路を測定し、並列ビア／配線による改善を加算していません。

| 経路 | 評価電流 | 配線抵抗@60℃ | 配線降下 | 最大トラック温度上昇の目安 |
| --- | ---: | ---: | ---: | ---: |
| USB → F1 | 550 mA | 17.08 mΩ | 9.39 mV | 2.58℃ |
| F1 → D1 | 550 mA | 17.60 mΩ | 9.68 mV | 0.51℃ |
| D1 → U2 VIN | 550 mA | 27.78 mΩ | 15.28 mV | 6.77℃ |
| L1出力 → モジュール | 500 mA | 67.78 mΩ | 33.89 mV | 1.29℃ |
| L1出力 → 左3V3ヘッダ | 500 mA | 59.48 mΩ | 29.74 mV | 1.29℃ |
| L1出力 → 右3V3ヘッダ | 500 mA | 25.42 mΩ | 12.71 mV | 0.51℃ |
| D1 → 左5Vヘッダ | 500 mA | 56.01 mΩ | 28.00 mV | 7.87℃ |
| D1 → 右5Vヘッダ | 500 mA | 27.46 mΩ | 13.73 mV | 7.87℃ |

温度上昇は `I=k ΔT^0.44 A^0.725`、外層k=0.048、内層k=0.024のIPC-2221経験式によるスクリーニングです。Aはmil²です。[式の説明](https://jlcpcb.com/blog/pcb-trace-width-guide)を参照。短い細幅部分にも全経路電流を適用しました。IPC-2152の認定評価や基板全体の熱流体解析ではありません。

### 入力電圧と保護部品

[F1の温度ディレーティング](https://www.bourns.com/docs/product-datasheets/mf-nsmf.pdf)は50℃で保持0.83 A、60℃で0.80 Aです。23℃のリフロー後抵抗上限0.23 Ωに対し、温間抵抗0.46 Ωを仮定すると550 mA時の降下0.253 V、損失0.139 Wになります。この温間抵抗は評価用仮定です。

[D1のデータシート](https://www.vishay.com/doc?88746=)に基づきVf=0.50 Vで評価しました。550 mA時の損失0.275 W、熱抵抗を保守的に150℃/Wと仮定した接合温度は周囲50℃で91.3℃です。

入力電圧予算は `4.75 − 0.50 − 0.55×(0.46 + 0.06246) − 0.010 = 3.953 V` です。U2の最小入力3.8 Vを上回り、この電圧・効率80%で3.3 V/500 mAを供給する入力電流は約0.522 Aです。USBの接続状態に応じた消費電流制限や突入電流の認証を意味しません。長いケーブルなどでコネクタ電圧が4.75 Vを下回る条件はこの500 mA定格計算に含みません。

### 降圧回路の発熱

出力1.65 W、効率80%を下限仮定とすると総変換損失は0.4125 Wです。この損失をすべてICで発生するものとして扱いました。

| 熱抵抗の仮定 | 周囲50℃での接合温度見積り |
| --- | ---: |
| データシート値89℃/W | 86.7℃ |
| 基板差を見込んだ150℃/W | **111.9℃** |

データシートの89℃/Wは単層2 ozの試験基板条件で、この基板で測定した値ではありません。効率80%もメーカー保証値ではなく、設計用の保守的な仮定です。150℃/Wで125℃以下に収まる損失上限は0.50 W、必要効率は約76.7%以上です。試作では損失・温度を測定し、この仮定を確認します。

## 5. DRC・ERCと保存した証拠

| チェック | 結果 |
| --- | --- |
| DRC `--all-track-errors --severity-all --refill-zones` | 違反0 |
| 未配線 | 0 |
| PCB／回路図の接続・部品・フィールド整合性 | 0 |
| ERC `--severity-all` | 違反0 |
| 本体下の禁止領域と負の試験 | 配線・ビア0、試験用配線とビアの両方を検出 |
| USBレイヤー・ビア・A/B経路の幾何長・直下GNDの独立チェック | 合格（A側はR11の端子間距離を含む） |

既存の一般ルール無効項目（missing_courtyard、track_not_centered_on_via、tuning_profile_track_geometries、footprint_filters_mismatch、footprint_type_mismatch）は継承しています。今回の違反解消のために例外登録・エラー除外・クリアランス引き下げは追加していません。全種類の検査を有効化したという意味ではありません。

カスタムルールにはL2への信号配線禁止、USBの表面限定・ビア禁止・幅・主区間のペア間隔・GND間隔・経路長・スキュー、電源の最小配線幅、SWの表面限定を登録しています。ENの短い低電流接続だけは0.30 mmとして明示しています。

回路図、表面配線、L2、3Dをレンダリングし、追加部品の接続とシルクを目視確認しました。3Dビューは傾斜30°で出力しています。LEDの部品値は赤／青指定ですが、共通ライブラリ3Dモデルの発光色は実部品色の保証ではありません。

## 6. 試作で閉じる項目

1. 指定スタックアップと90 Ω差動の製造業者確認、TDRクーポン、両向きUSB接続／書込み／アイパターン。追加したR11の実装とパッケージ不連続も確認。
2. C1/C2/C8の具体的な採用品番と実効容量・ESR、入力突入電流、0～500 mAの負荷過渡、立ち上がり、短絡保護。
3. 周囲50℃・500 mA連続時のIC／ダイオード／PTC／インダクタの温度と電源効率。実測効率が80%を下回る、またはIC接合温度見積りが125℃を超える場合は熱設計を再評価。
4. Wi-Fi送信時の電圧最低値・リップル、USBとRFへのスイッチングノイズ、PSRAM・LED・RESET/BOOT動作。

## 再実行コマンド

KiCad Pythonは `wx.App(False)` を必要とするため、スクリプト内で初期化しています。以下はプロジェクト親フォルダーで実行します。

```sh
python3 scripts/verify_project.py
/Applications/KiCad/KiCad.app/Contents/Frameworks/Python.framework/Versions/3.9/bin/python3 scripts/verify_usb_keepout.py
/Applications/KiCad/KiCad.app/Contents/Frameworks/Python.framework/Versions/3.9/bin/python3 scripts/audit_electrical_layout.py
/Applications/KiCad/KiCad.app/Contents/Frameworks/Python.framework/Versions/3.9/bin/python3 scripts/export_ground_geometry.py
# NumPy/SciPy/Shapely/Matplotlibを導入したPythonで実行
python scripts/usb_cross_section.py --step .0025 --output interactive/review/usb-section-fine.json --plot interactive/review/usb-cross-section.png
python scripts/ground_plane_dc.py
```

数値モデルは `../scripts/usb_cross_section.py`、`../scripts/ground_plane_dc.py`。PCBを新たに生成する `fix_usb_underbody.py` と旧版の `upgrade_buck.py` は、既存のGUI編集を上書きするため通常の検証手順には含めません。

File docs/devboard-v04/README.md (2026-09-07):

# DevBoard v0.4の履歴資料

このフォルダーはMatrix5端子への移行前の設計・検証記録です。現行設計は [Matrix6 v0.5](../../README.md)、CADは [hardware/Matrix6](../../hardware/Matrix6) にあります。

v0.4は35.56 × 61 mm、ヘッダー列間30.48 mmで、Matrix5シールドの位置・端子割り当てに対応していません。ヘッダーの外部5 V入力を説明した記述も旧設計の条件です。**現行のH1.1/H2.1は出力専用**で、給電条件は [v0.5互換性資料](../matrix5-compatibility.md) を参照してください。

[電気設計レビュー](electrical-review.md)は、引き継いだUSB形状・層構成・降圧回路の設計経緯を残すものです。このフォルダーの画像、DRC/ERC、SHA-256、元プロジェクト名や元のパスはv0.4当時の記録であり、現在のCADに対する検証ではありません。現行の結果は [../validation](../validation) にあります。

移行前のCADは初期インポートのコミット `ee580b181c5c248c455f0519c6c52200018bf0b3` に保存されています。

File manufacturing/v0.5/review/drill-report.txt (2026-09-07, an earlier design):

Drill report for Matrix6.kicad_pcb
Created on 2026-09-07T17:57:41

Copper Layer Stackup:
    =============================================================
    L1 :  F.Cu                      front
    L2 :  In1.Cu                    in1
    L3 :  In2.Cu                    in2
    L4 :  B.Cu                      back

Drill file 'Matrix6-PTH.drl' contains
    plated through holes:
    =============================================================
    T1  0.200mm  0.0079"  (12 holes))
    T2  0.300mm  0.0118"  (130 holes))
    T3  0.600mm  0.0236"  (4 holes)  (with 4 slots)
    T4  1.000mm  0.0394"  (40 holes))

    Total plated holes count 186

Drill file 'Matrix6-NPTH.drl' contains
    unplated through holes:
    =============================================================
    T1  0.650mm  0.0256"  (2 holes))

    Total unplated holes count 2

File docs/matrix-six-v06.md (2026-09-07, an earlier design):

# Matrix Six v0.6

SDスロットの口の前にLiPoコネクタ・充電部品が来ていた配置を修正しました。J2を反転し、口をアンテナ側（KiCadの−Y）へ向けています。裏面のX=109.9〜125.7、Y=100.5〜123.0 mmは部品配置禁止領域です。標準フットプリント内の金属接触部の銅箔禁止領域も維持しています。全裏面部品のコートヤードとこの通路の重なりは0です。[寸法図](validation/sd-access.svg)、[数値検証](validation/sd-access.json)

名前をMatrix Sixに変更し、SDとLiPo回路を追加しました。USBの銅配線・本体下禁止領域、4層スタックアップ、L2の連続GND、40か所のシールドヘッダー位置は保持しています。自動配線は使用していません。新規配線は `scripts/revise_matrix_six.py` と `scripts/matrix_six_rear_routes.py` に明示した座標です。

## 回路

- SD: Hirose DM3AT-SF-PEJM5。CS=IO10、MOSI=IO11、CLK=IO12、MISO=IO13。CMDとDAT0〜3は各10 kΩで3V3へプルアップ。検出接点は未接続。SPI 20 MHz以下を立ち上げ条件とし、最初は低速で書き込み・読み出しとWi-Fi併用時の安定性を確認します。[Espressifのプルアップ要件](https://docs.espressif.com/projects/esp-idf/en/latest/esp32s3/api-reference/peripherals/sd_pullup_requirements.html)
- 3V3: TPS63001DRCR、SRN4018-2R2M（2.2 µH）。VINAは100 Ωと100 nFでフィルタ。入力22 µF、出力22 µF×2。L2に信号は配線していません。[TIデータシート](https://www.ti.com/lit/ds/symlink/tps63000.pdf)、[Bourns](https://www.bourns.com/docs/product-datasheets/srn4018.pdf)
- 充電: MCP73831T-2ACI/OT、RPROG=10 kΩで公称100 mA。1S 4.2 V用。充電器のSTATは未使用で、LEDは指定の赤POWERと青PIN 48の2個です。[Microchipデータシート](https://ww1.microchip.com/downloads/en/DeviceDoc/20001984g.pdf)
- 電源切替: USB→D1→VSYS、電池→AO3401A→VSYS。PMOSのゲートをUSBへ、ドレインを電池、ソースをVSYSへ接続。電池負荷を充電端子から分離します。[Microchip AN1149](https://ww1.microchip.com/downloads/en/AppNotes/01149c.pdf)、[AO3401A](https://www.aosmd.com/pdfs/datasheet/AO3401A.pdf)
- 電池端子: JST S2B-PH-K-S(LF)(SN)。1番VBAT、2番GND。H2.20もVBATです。保護回路付き3.7 V／4.2 V、500 mAh以上、1 A以上の放電定格を基準としました。電池未接続でもUSBで動作する構成です。逆極性防止、セル温度センサー、3 Vでの電池遮断はありません。電池側の保護と仕様に従います。

## 検証と残る確認

ERC、全重大度のDRC、未配線、回路図等価性は0。USBは表面のみ・ビア0、v0.4と同じ銅形状。L2は1領域で、USB直下13,182サンプルに欠損がありません。Matrix5の11シールドの使用端子は一致します。

電源の計算条件は、周囲50℃、3V3の合計500 mA、USB時は追加VBUS負荷100 mAと充電最大110 mA、電池時は入力800 mAでのスクリーニングです。3V3の配線降下はモジュールまで約53.5 mV、H1まで約31.4 mV。電池系のL3配線は1.2 mmへ広げました。MCP73831の最悪条件例は5.25 V入力・3.0 V電池・110 mAで約0.248 W、θJA=230℃/Wを仮定した接合温度約107℃です。温度・効率・銅厚等の仮定を含み、組立基板の実測値ではありません。[電源計算](validation/electrical-audit.json)

Samsungの公開DCバイアス曲線を確認しました。初期公差−20%、温度−15%、経年余裕−10%を掛けたスクリーニングで、5.25 V時は約6.27 µF、3.3 V時の2個合計は約18.23 µFとなり、入力4.7 µF・出力15 µFの設計目標を上回ります。これはメーカー典型曲線と仮定の組合せであり、全条件の保証値ではありません。[容量確認](validation/capacitor-screen.json)、[Samsung](https://product.samsungsem.com/mlcc/CL21A226MAQNNN.do)

製造前に残る確認は、部品調達と代替品の再評価、両面実装の向きと極性、JLCPCBの実スタックアップとUSBインピーダンスです。公称容量から実効容量を保証していません。U1/U2のサーマルビアには平坦な充填・キャップ仕上げが必要です。実機では、カード挿抜、筐体・シールドの高さ、USB通信、無線とSD同時動作、電源切替、充電終了、負荷・温度・USB波形を確認してください。

v0.5のアップロード済みBOM/CPL・Gerberをv0.6へ混用しないでください。v0.6は両面実装の見積もり用設計です。注文・決済はしていません。

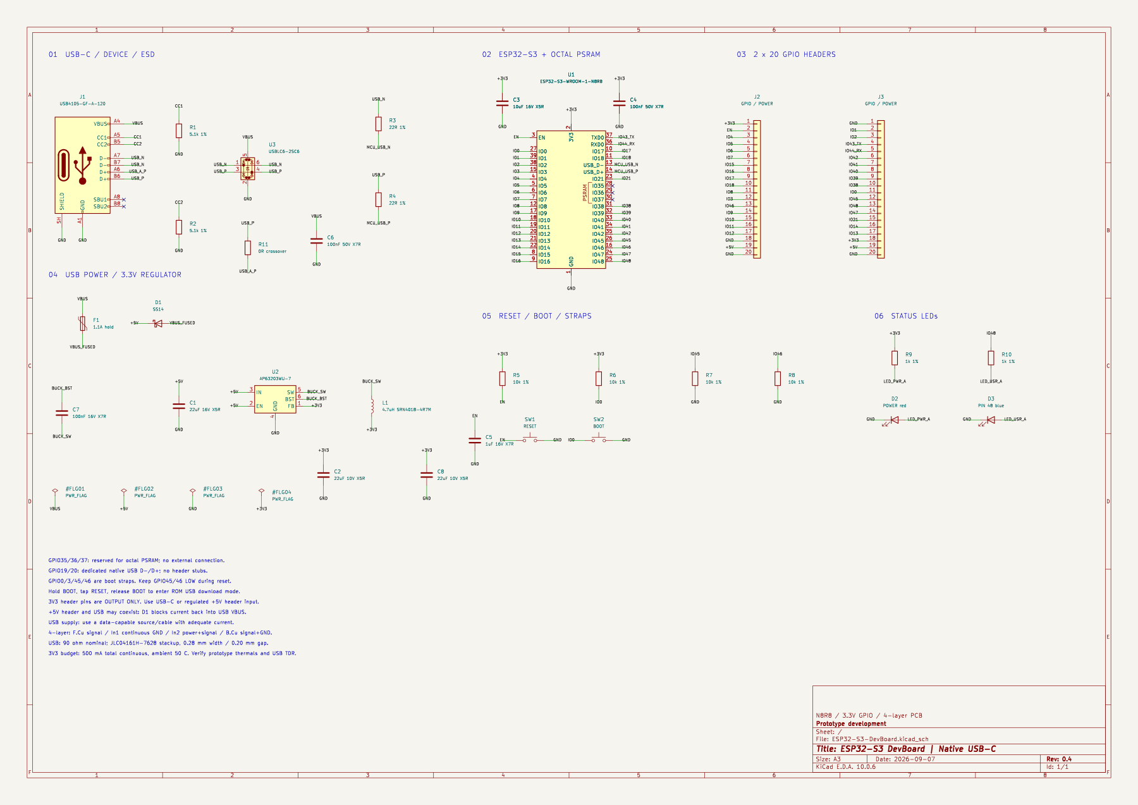
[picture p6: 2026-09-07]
docs/devboard-v04/review/schematic-final.png

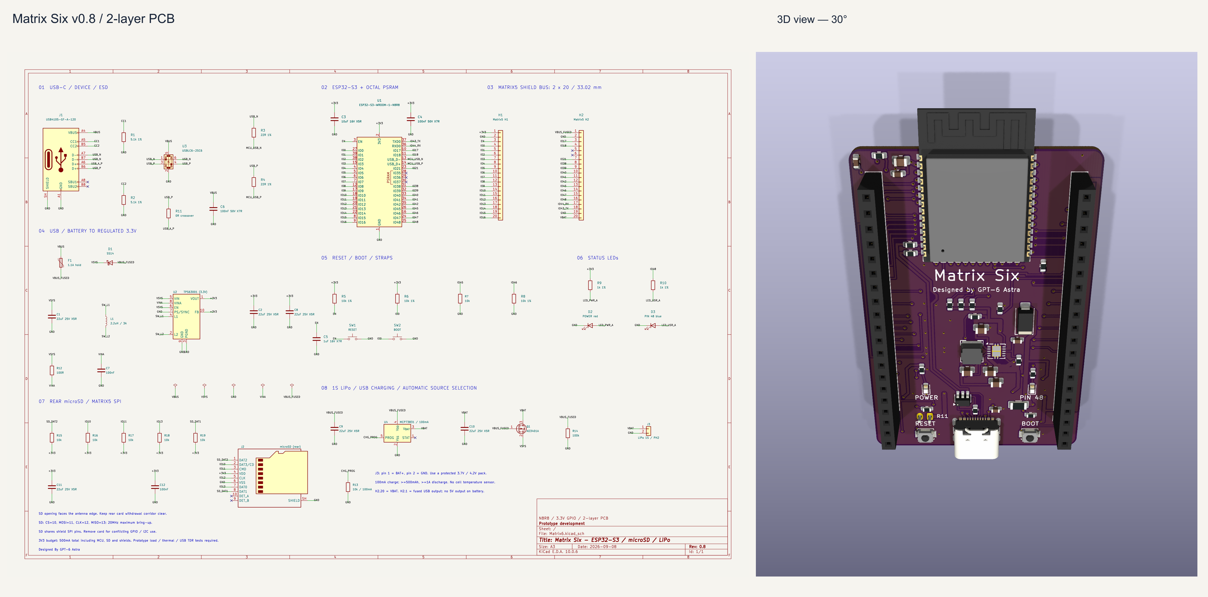
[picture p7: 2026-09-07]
docs/validation/schematic-and-3d.png

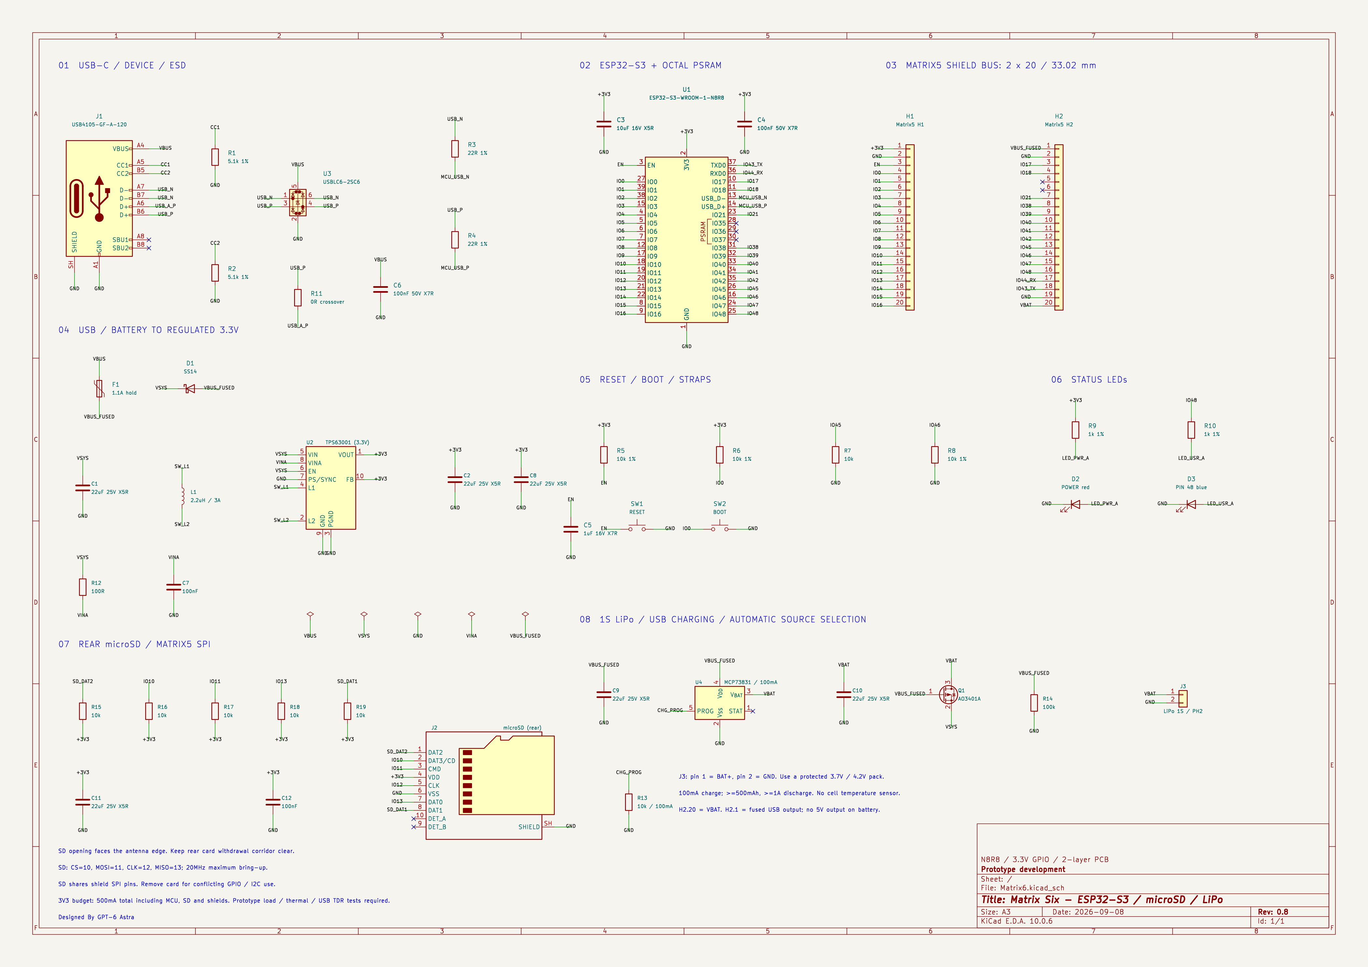
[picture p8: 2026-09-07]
docs/validation/schematic.png

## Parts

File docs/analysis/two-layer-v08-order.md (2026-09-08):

# v0.8 2層版の発注準備（2026-09-08）

中央文字・R8移動を含むCADコミット `d0ea1e0` のGerber、BOM、CPLをJLCPCBへ新規アップロードし、決済画面まで準備しました。支払い完了と製造承認は確認していません。

- 注文番号：`W2026090808083223`
- PCB：`Y263-2423180A`
- PCBA：`SMT026090860012-2423180A`
- アップロード識別子：`457b67c9c2a34bfcb186788817f25ab9`
- Gerber SHA-256：`89d3072399df033898e433e7c2f0e9a7e75ffe56867b2b2d70deb4cf3636ab8f`
- PCB SHA-256：`20be22f195de4a42cf2f9902171f88ed01ce740b4684df816ad5f17b66c79c9f`

## 数量・条件

基板5枚、Standard両面実装2枚。2層・公称1.6 mm・両面1 oz・紫・白シルク・S1000H TG155・ENIG 1u。原板40.64 × 61 mm、JLC追加レール込み70.64 × 71 mm。最小穴径0.3 mm料金区分、エポキシ充填・銅キャップ、Horizontal Electroless Copper Plating、フライングプローブ全数検査。製造図面・実装配置の確認あり、自動承認しない設定を選択しました。

26 BOMグループ、48部品（表37／裏11）は全て指定型番のまま選択済み。USB J1（C5184243）も数量2・選択済みを確認しました。BOM再読込み後は26種類検出・26種類確認済み、全26行が選択済みでした。部品置換は行っていません。在庫は確認時点の情報で、製造開始を保証するものではありません。

JLCの表裏プレビューで中央文字、R8のモジュール右側配置、縦のH1/H2、裏面microSDを確認しました。一部JLC 3Dモデル（U1/J1/J3等）の原点に差があるため、外観だけを根拠にCPL座標を変更していません。CAD実装基準図・表裏3D画像を添付し、全パッド・極性とSD挿入口を実装担当者が照合するよう備考に指定しました。JLCの最終DFM/CAM配置承認は未実施です。

## 決済画面の表示額

| 項目 | USD |
|---|---:|
| 基板5枚 | 83.27 |
| 部品・両面実装2枚 | 162.40 |
| 商品合計 | 245.67 |
| DHL Express送料 | 18.38 |
| PCBAクーポン | -6.00 |
| **決済画面合計** | **258.05** |

支払方法は利用者によるカード入力中で、こちらから決済操作はしていません。支払い完了は未確認です。OCSの見積表示は8.79ドルでしたが、最終確認した決済画面ではDHL（1–3営業日）が選択されていました。

レール除去費2.30ドルは上記合計に含まれず、実装備考に伴う追加費用も審査後確定です。輸入税・通関手数料等は配送条件に従います。製造日数表示は基板3日・実装4–5日、追加オプションで1日追加。カートの出荷目安は2026-09-16でしたが、支払い・資料確認・審査により変わります。

## 保存した備考

PCB備考（196文字）：

> See fabrication JPG in ZIP. Fill/copper-cap thermal/in-pad vias incl.12 U1 pad41 PTHs (not leads). Keep connector holes/slots/NPTH open. Preserve USB coplanar GND. 2L,1.6mm. CAM approval required.

実装備考（442文字）：

> Matrix Six v0.8: centered logo and moved R8. Assemble all 48 parts (37 top/11 bottom). Match attached CAD/CPL pads and polarity; U1/J1/J3 web 3D origins may differ. H1/H2 vertical. J2 bottom microSD mouth faces antenna/top; keep withdrawal corridor clear. J3 bottom, pin1 BAT+, pin2 GND. CPL rotation corrections are already included. Remove rails without damaging antenna/USB/SD. Send placement preview for customer approval before assembly.

添付：`Matrix6-assembly-reference.png`、`pcb-3d-top.png`、`pcb-3d-bottom.png`。製造条件JPGはアップロード済みGerber ZIPにも含まれます。

旧4層v0.7注文 `W2026090719552210` は別注文として残り、今回変更・キャンセル・支払いをしていません。2層試作版は管理インピーダンス保証を前提にせず、実機USB・電源・熱試験は引き続き必要です。

出典：[最新注文の決済ページ](https://trade.jlcpcb.com/checkout/payMethod?systemType=order_pcb&calType=PAY&batchNum=W2026090808083223)、[アップロード済みPCBA](https://cart.jlcpcb.com/smt-order/?pcbFileNo=457b67c9c2a34bfcb186788817f25ab9)。

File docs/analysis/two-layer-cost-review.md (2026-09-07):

# Matrix Six：2層化と製造コストの比較

> **履歴資料：v0.7の4層設計を対象にした事前調査です。** この後、ユーザーの2層化依頼により[v0.8の再設計](../matrix-six-v08.md)を完了しました。以下の配線数・穴径・金額はv0.7の記録であり、現行2層版の仕様・見積もりではありません。

2026-09-08、v0.7の保存済みCADとJLCPCBの見積画面を確認しました。**2層への再設計は技術的な選択肢ですが、現在の配線をそのまま2層へ減らすことはできません。コスト目的なら、まず4層の製造条件を実データに合わせる方法を推奨します。**

この調査ではCAD、発注済みの未払い注文、製造用Gerber/BOM/CPLを変更していません。比較用の見積画面を作成した段階で、別注文は作成していません。

## 2層化に必要な変更

- 内層In2.Cuには38ネット・110線分、合計580.659 mmの配線があります。表裏への再配線と、GNDを確保するための部品配置の再検討が必要です。オートルーターは使用しません。
- 現在のUSB直下のGNDはIn1.Cuで13,182検査点すべてを覆っています。B.Cuの既存GNDでは6,463点に欠損があり、そのままUSBの参照面にはできません。USBを表面・ビアなしとする条件を維持し、裏面に連続したGND経路を確保する再設計が必要です。
- 4層での約91.1 Ωという断面計算結果は、2層へ流用できません。基板厚、材料、配線幅・間隔・周囲GNDを再計算する必要があります。
- ESP32-S3の設計ガイドは2層構成も扱っています。一方、USBについては90 Ω±10%、等長の並行配線、連続した参照面を求めています。[Espressif設計ガイド](https://docs.espressif.com/projects/esp-hardware-design-guidelines/en/latest/esp32s3/pcb-layout-design.html)
- JLCPCBの標準FR-4の管理インピーダンス対応は4層以上です。2層にする場合は、設計計算と試作・測定による検証へ条件を変更する必要があります。2層版はまだ製造承認できる状態ではありません。[JLCPCB製造能力](https://jlcpcb.com/capabilities/pcb-capabilities/)

Matrix5の端子位置、R2外形、USB脇のRESET/BOOT、下側のPOWER/PIN 48 LED、裏面microSDの抜き差し空間、LiPo充電・電源切替は維持する前提です。両面実装のままなので、2層化だけでは実装工程の基本費用はなくなりません。

## 4層のままで削減できる費用

実データの通常ビアは150個すべて穴径0.3 mm／銅箔径0.6 mmです。最小穴はU1のサーマルPTH 12個の0.2 mmで、銅箔径は0.6 mmあります。前回の見積もりでは `0.2mm/(0.3/0.35mm)` という微細条件を選択していましたが、実形状より厳しい条件です。

JLCPCBの見積画面の説明では、多層基板で銅箔径が0.45 mm以上の場合、0.2 mm穴にも微細ビア追加料金はかかりません。標準料金区分で比較したところ、微細ビア料金とそれに伴う4線式Kelvin試験料金がなくなりました。通常のフライングプローブ全数導通試験は維持しています。実際の穴径は0.2 mmのままで、ドリルデータを0.3 mmへ変更する意味ではありません。CAM確認時にこの穴・銅箔寸法と料金区分を明示する必要があります。[見積画面の製造条件](https://cart.jlcpcb.com/quote)、[穴径・銅箔径の規定](https://jlcpcb.com/capabilities/pcb-capabilities/)

比較は基板5枚、両面実装2枚、JLC追加レール込み70.64×71 mm、1.6 mm、紫、白シルク、ENIG 1u、FR4 TG155、外層1 oz／内層0.5 oz、JLC04161H-7628、インピーダンス管理±10%、エポキシ充填・銅キャップ、Horizontal Electroless Copper Plating、製造ファイル確認ありの条件です。

| 基板費の内訳 | 現行注文 | 比較画面 |
|---|---:|---:|
| 基本料金 | $7.00 | $7.00 |
| ビア充填・キャップ | $17.04 | $17.04 |
| ENIG | $17.00 | $17.00 |
| 材料指定 | $3.41 | $3.41 |
| 紫 | $5.00 | $5.00 |
| インピーダンス管理 | $32.84 | $32.84 |
| ビアめっき方法 | $3.35 | $3.35 |
| 製造ファイル確認 | $1.04 | $1.04 |
| 微細ビア | $17.04 | $0.00 |
| 4線式Kelvin試験 | $16.75 | $0.00 |
| **基板5枚** | **$120.47** | **$86.68** |

**基板費の削減は$33.79（約28%）**。実装費$162.42・OCS送料$8.79・割引$6.00が同じ場合、合計は$285.68から**約$251.89（約12%減）**になります。$86.68は比較画面の表示値で、$251.89は既存実装費・送料・割引を用いた計算値です。部品の再見積もり・CAMの料金区分確認はまだ行っていません。決済手数料、基板分割等の審査後費用、輸入時費用は含みません。

さらにビア充填を不要にするパッド・ペースト・放熱構造の変更も検討できますが、製造方法だけを切り替えるのは不適切です。色変更は別の外観選択になります。これらを今回の$33.79削減へ混ぜていません。

## 再現用データ

- [配線と穴の実測JSON](two-layer-feasibility.json)
- `scripts/review_two_layer_feasibility.py` をKiCad Pythonで実行。CADを変更せず、既存の充填済みGNDと配線を測定します。
- PCB SHA-256: `fabde2cfe1d13ff8f631c0265ae2106bbdb555769dfc1150de94dfcd200140ec`

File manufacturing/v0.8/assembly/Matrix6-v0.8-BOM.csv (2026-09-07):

Comment | Designator | Footprint | JLCPCB Part # | Manufacturer Part Number | Quantity
CL21A226MAQNNNE | C1,C2,C8,C9,C10,C11 | 0805 | C45783 | CL21A226MAQNNNE | 6
GRM21BR61H106KE43L | C3 | 0805 | C440198 | GRM21BR61H106KE43L | 1
CC0603KRX7R9BB104 | C4,C6,C7,C12 | 0603 | C14663 | CC0603KRX7R9BB104 | 4
CL10B105KO8NNNC | C5 | 0603 | C59782 | CL10B105KO8NNNC | 1
SS14-E3/61T | D1 | D_SMA | C47460 | SS14-E3/61T | 1
XL-1608SURC-06 | D2 | 0603 | C965799 | XL-1608SURC-06 | 1
XL-1608UBC-04 | D3 | 0603 | C965807 | XL-1608UBC-04 | 1
MF-NSMF110/16X-2 | F1 | Fuse_1206_3216Metric | C25415531 | MF-NSMF110/16X-2 | 1
254PM-1x20P-V | H1,H2 | PinSocket_1x20_P2.54mm_Vertical | C53202183 | 254PM-1x20P-V | 2
USB4105-GF-A-120 | J1 | USB4105_NoUnderbodyCopper | C5184243 | USB4105-GF-A-120 | 1
DM3AT-SF-PEJM5 | J2 | microSD_HC_Hirose_DM3AT-SF-PEJM5 | C114218 | DM3AT-SF-PEJM5 | 1
S2B-PH-K-S(LF)(SN) | J3 | JST_PH_S2B-PH-K_1x02_P2.00mm_Horizontal | C173752 | S2B-PH-K-S(LF)(SN) | 1
SRN4018-2R2M | L1 | L_Bourns-SRN4018 | C913207 | SRN4018-2R2M | 1
AO3401A | Q1 | SOT-23 | C15127 | AO3401A | 1
0603WAF5101T5E | R1,R2 | 0603 | C23186 | 0603WAF5101T5E | 2
0603WAF220JT5E | R3,R4 | 0603 | C23345 | 0603WAF220JT5E | 2
0603WAF1002T5E | R5,R6,R7,R8,R13,R15,R16,R17,R18,R19 | 0603 | C25804 | 0603WAF1002T5E | 10
0603WAF1001T5E | R9,R10 | 0603 | C21190 | 0603WAF1001T5E | 2
CRCW06030000Z0EA | R11 | 0603 | C844915 | CRCW06030000Z0EA | 1
0603WAF1000T5E | R12 | 0603 | C22775 | 0603WAF1000T5E | 1
0603WAF1003T5E | R14 | 0603 | C25803 | 0603WAF1003T5E | 1
B3U-1000P | SW1,SW2 | SW_SPST_B3U-1000P | C231329 | B3U-1000P | 2
ESP32-S3-WROOM-1-N8R8 | U1 | ESP32-S3-WROOM-1_Edge | C2913201 | ESP32-S3-WROOM-1-N8R8 | 1
TPS63001DRCR | U2 | Texas_DRC0010J | C28060 | TPS63001DRCR | 1
USBLC6-2SC6 | U3 | SOT-23-6 | C7519 | USBLC6-2SC6 | 1
MCP73831T-2ACI/OT | U4 | SOT-23-5 | C424093 | MCP73831T-2ACI/OT | 1

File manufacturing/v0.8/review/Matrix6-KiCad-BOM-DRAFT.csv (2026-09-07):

Reference | Value | Footprint | MPN | Manufacturer | Quantity
C1 | 22uF 25V X5R | Capacitor_SMD:C_0805_2012Metric | CL21A226MAQNNNE |  | 1
C2 | 22uF 25V X5R | Capacitor_SMD:C_0805_2012Metric | CL21A226MAQNNNE |  | 1
C3 | 10uF 16V X5R | Capacitor_SMD:C_0805_2012Metric |  |  | 1
C4 | 100nF 50V X7R | Capacitor_SMD:C_0603_1608Metric |  |  | 1
C5 | 1uF 16V X7R | Capacitor_SMD:C_0603_1608Metric |  |  | 1
C6 | 100nF 50V X7R | Capacitor_SMD:C_0603_1608Metric |  |  | 1
C7 | 100nF | Capacitor_SMD:C_0603_1608Metric |  |  | 1
C8 | 22uF 25V X5R | Capacitor_SMD:C_0805_2012Metric | CL21A226MAQNNNE |  | 1
C9 | 22uF 25V X5R | Capacitor_SMD:C_0805_2012Metric | CL21A226MAQNNNE |  | 1
C10 | 22uF 25V X5R | Capacitor_SMD:C_0805_2012Metric | CL21A226MAQNNNE |  | 1
C11 | 22uF 25V X5R | Capacitor_SMD:C_0805_2012Metric | CL21A226MAQNNNE |  | 1
C12 | 100nF | Capacitor_SMD:C_0603_1608Metric |  |  | 1
D1 | SS14 | Diode_SMD:D_SMA | SS14-E3/61T | Vishay | 1
D2 | POWER red | LED_SMD:LED_0603_1608Metric |  |  | 1
D3 | PIN 48 blue | LED_SMD:LED_0603_1608Metric |  |  | 1
F1 | 1.1A hold | Fuse:Fuse_1206_3216Metric | MF-NSMF110/16X-2 | Bourns | 1
H1 | Matrix5 H1 | Connector_PinSocket_2.54mm:PinSocket_1x20_P2.54mm_Vertical |  |  | 1
H2 | Matrix5 H2 | Connector_PinSocket_2.54mm:PinSocket_1x20_P2.54mm_Vertical |  |  | 1
J1 | USB4105-GF-A-120 | DevBoard:USB4105_NoUnderbodyCopper |  |  | 1
J2 | microSD (rear) | Connector_Card:microSD_HC_Hirose_DM3AT-SF-PEJM5 | DM3AT-SF-PEJM5 |  | 1
J3 | LiPo 1S / PH2 | Connector_JST:JST_PH_S2B-PH-K_1x02_P2.00mm_Horizontal | S2B-PH-K-S(LF)(SN) |  | 1
L1 | 2.2uH / 3A | Inductor_SMD:L_Bourns-SRN4018 | SRN4018-2R2M |  | 1
Q1 | AO3401A | Package_TO_SOT_SMD:SOT-23 | AO3401A |  | 1
R1 | 5.1k 1% | Resistor_SMD:R_0603_1608Metric |  |  | 1
R2 | 5.1k 1% | Resistor_SMD:R_0603_1608Metric |  |  | 1
R3 | 22R 1% | Resistor_SMD:R_0603_1608Metric |  |  | 1
R4 | 22R 1% | Resistor_SMD:R_0603_1608Metric |  |  | 1
R5 | 10k 1% | Resistor_SMD:R_0603_1608Metric |  |  | 1
R6 | 10k 1% | Resistor_SMD:R_0603_1608Metric |  |  | 1
R7 | 10k | Resistor_SMD:R_0603_1608Metric | 0603WAF1002T5E |  | 1
R8 | 10k 1% | Resistor_SMD:R_0603_1608Metric |  |  | 1
R9 | 1k 1% | Resistor_SMD:R_0603_1608Metric |  |  | 1
R10 | 1k 1% | Resistor_SMD:R_0603_1608Metric |  |  | 1
R11 | 0R crossover | Resistor_SMD:R_0603_1608Metric | CRCW06030000Z0EA | Vishay | 1
R12 | 100R | Resistor_SMD:R_0603_1608Metric | 0603WAF1000T5E |  | 1
R13 | 10k / 100mA | Resistor_SMD:R_0603_1608Metric | 0603WAF1002T5E |  | 1
R14 | 100k | Resistor_SMD:R_0603_1608Metric | 0603WAF1003T5E |  | 1
R15 | 10k | Resistor_SMD:R_0603_1608Metric | 0603WAF1002T5E |  | 1
R16 | 10k | Resistor_SMD:R_0603_1608Metric | 0603WAF1002T5E |  | 1
R17 | 10k | Resistor_SMD:R_0603_1608Metric | 0603WAF1002T5E |  | 1
R18 | 10k | Resistor_SMD:R_0603_1608Metric | 0603WAF1002T5E |  | 1
R19 | 10k | Resistor_SMD:R_0603_1608Metric | 0603WAF1002T5E |  | 1
SW1 | RESET | Button_Switch_SMD:SW_SPST_B3U-1000P |  |  | 1
SW2 | BOOT | Button_Switch_SMD:SW_SPST_B3U-1000P |  |  | 1
U1 | ESP32-S3-WROOM-1-N8R8 | DevBoard:ESP32-S3-WROOM-1_Edge |  |  | 1
U2 | TPS63001 (3.3V) | Package_SON:Texas_DRC0010J | TPS63001DRCR |  | 1
U3 | USBLC6-2SC6 | Package_TO_SOT_SMD:SOT-23-6 |  |  | 1
U4 | MCP73831 / 100mA | Package_TO_SOT_SMD:SOT-23-5 | MCP73831T-2ACI/OT |  | 1

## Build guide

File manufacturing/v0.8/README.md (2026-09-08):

# Matrix Six v0.8 — 2層・四隅R2 mm

再配線済み2層版の試作見積もり用データです。DRC・ERC・未配線・回路図整合性は0件。Matrix5互換端子、裏面microSDの抜き差し空間、LiPo充電・切替、R2外形を維持しました。

- [2層Gerber ZIP](Matrix6-v0.8-Gerber.zip)
- [BOM](assembly/Matrix6-v0.8-BOM.csv) / [CPL](assembly/Matrix6-v0.8-CPL.csv)
- [実装基準図](review/Matrix6-assembly-reference.png) / [製造条件](review/Matrix6-fabrication-requirements.svg)
- [出力検証](assembly/export-validation.json) / [CAD・出力のハッシュ](source-manifest.json)
- [設計と検証範囲](../../docs/matrix-six-v08.md)

## 見積もり条件

2層FR4、公称1.6 mm、両面1 oz、40.64 × 61 mm、四隅R2 mm。従来の外観は紫・白シルク・ENIG 1uです。基板5枚／両面実装2枚を比較の基準とし、JLC追加レールは部品の張り出し・両面実装条件に合わせて確認します。

銅箔ファイルはF_Cu.gtlとB_Cu.gblの2枚のみ。内層データはありません。最小完成穴径0.30 mm、通常ビア径0.60 mm、U1の12放熱穴は径0.30／パッド0.80 mm。放熱・パッド内ビアのエポキシ充填と銅キャップは必要です。U1の放熱穴は部品挿入穴として開口しないようCAMへ指定し、コネクタ穴・USB長穴・NPTHは開口します。

USB差動は表面のみ・ビア0、均一部分の幅0.380／線間0.180／両脇GNDまで0.200 mm。断面計算は約90.3Ωですが、標準2層での管理インピーダンス保証は前提にしていません。4層用7628スタックを指定しないでください。GND帯を保ち、形状変更は製造前に照合します。

## 実装と版の注意

48部品・26 BOMグループ。部品型番は前版の選定を継承しました。配置変更があるため、旧v0.7のCPLは使用できません。H1/H2のJLCモデル回転補正+90°、J2の+180°は継承し、今回の部品移動・R6/C11の表裏変更を新しいCPLに反映しています。

U1/J1/J3等のJLCモデル原点とパッドの差があるため、プレビュー上の外観だけでは判断せず、実装基準図と全パッド・極性を照合します。アンテナ張り出し6.25 mm、microSDの口はアンテナ側、J3は1番BAT+／2番GNDです。

2026-09-08、R8移動・文字中央寄せ後の本フォルダーのGerber/BOM/CPLをJLCPCBへアップロードしました。全26種類・48部品は指定型番で選択済み。表裏プレビューを確認し、CAD実装基準図と表裏3D画像を添付しました。最終DFM/CAM配置承認は未実施です。

最新注文は `W2026090808083223`（PCB `Y263-2423180A`）。基板5枚 **$83.27**、両面実装2枚 **$162.40**、DHL送料と$6クーポン適用後の決済画面は **$258.05** です。別途レール除去費$2.30と審査後に確定する追加費用があります。支払い完了は未確認です。[発注準備の記録](../../docs/analysis/two-layer-v08-order.md)を参照してください。

元のv0.7は別の4層注文として残っており、今回変更・キャンセル・支払いをしていません。

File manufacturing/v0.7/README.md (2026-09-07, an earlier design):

# Matrix Six v0.7 — 四隅R2 mm

40.64 × 61.00 mmの外接寸法を維持し、四隅を半径2 mmに丸めました。v0.6から部品・配線の座標は変更していません。GNDベタを新外形で再充填し、DRC・ERC・未配線・回路図整合性はすべて0件。Matrix5端子40位置と全11シールドの使用ピン、USB、SDアクセス経路も検証済みです。

- [丸角版Gerber ZIP](Matrix6-v0.7-Gerber.zip)
- [BOM](assembly/Matrix6-v0.7-BOM.csv) / [CPL](assembly/Matrix6-v0.7-CPL.csv)
- [実装基準図](review/Matrix6-assembly-reference.png) / [製造条件](review/Matrix6-fabrication-requirements.svg)
- [出力検証](assembly/export-validation.json) / [CAD・出力ファイルのハッシュ](source-manifest.json)

旧v0.6 Gerberは角が直角です。丸角版の発注にはこのv0.7を使います。BOM/CPLはv0.6から内容を保持し、H1/H2のJLCモデル回転+90°、J2の+180°も含みます。

基板5枚・両面実装2枚。4層FR4 TG155・1.6 mm・紫・白シルク・ENIG 1u・外層1 oz／内層0.5 oz。JLC04161H-7628、USB差動90Ω±10%、ビアのエポキシ充填と銅キャップ、0.2 mm穴、4線式Kelvin試験を指定します。

U1/J1/J3等はJLCモデルの表示原点とパッド位置のずれがあり、JLCPCBの修正済み実装確認図で全パッド・極性を照合してから製造承認が必要です。アンテナの張り出しは6.25 mm、SD挿入口はアンテナ側、J3は1番BAT+／2番GNDでUSB端側に挿入口があります。製造ファイル・実装位置は自動承認しません。

2026-09-07、v0.7のGerber・BOM・CPLをJLCPCBへアップロードし、全26部品グループを選択しました。丸角とH1/H2の縦向き、J2の挿入口方向をプレビューで確認し、CAD実装基準図・裏面3D図・SDアクセス図を添付しています。旧v0.6の未払い注文はファイル差し替えのため取り消し、新しいv0.7注文を決済待ちにしました。支払い・製造承認は未実施です。

決済画面の見積もりは **$285.68**（基板$120.47＋実装$162.42＋OCS送料$8.79−クーポン$6.00）。前の直角版と同額です。決済方法の手数料・輸入時の税等は別です。見積もり画面には、基板分割$2.30と実装備考に関する費用がレビュー後に別途確定する旨も表示されています。

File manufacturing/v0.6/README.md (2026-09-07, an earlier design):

# Matrix Six v0.6 — JLCPCB見積もり

修正済み裏面SD／LiPo／充電／電源切替を含む48部品の両面実装用データです。旧v0.5のBOM/CPL・Gerberとは混用できません。注文・決済は未実施です。

- [Gerber ZIP](Matrix6-v0.6-Gerber.zip)
- [JLCPCB BOM](assembly/Matrix6-v0.6-BOM.csv) / [CPL](assembly/Matrix6-v0.6-CPL.csv)
- [出力の照合結果](assembly/export-validation.json) / [元CADとファイルのハッシュ](source-manifest.json)
- [ドリル表](review/drill-report.txt) / [製造指示](review/Matrix6-fabrication-requirements.svg)
- [実装基準図・パッド1とコネクタ方向](review/Matrix6-assembly-reference.png)

基板5枚、実装2枚を見積もります。FR-4・4層・1.6 mm・紫・ENIG・外層1 oz／内層0.5 oz、JLC04161H-7628相当、USB差動90 Ωを指定。U1/U2のサーマルビアを平坦に充填・銅キャップし、コネクタの部品穴は開口を保持します。

Top 37部品、Bottom 11部品。J3とH1/H2はスルーホール接続を含みます。ヘッダーとSD/JSTの配置原点は本体中心に補正しています。JLCPCBの選択モデルに合わせ、H1/H2はKiCad角度に+90°、J2は+180°を適用しました。再アップロード後、ヘッダーが縦、SDの挿入口がアンテナ側であることを確認しました。

2026-09-07にライブ画面で全26グループを選択済み。BOMのLCSC番号に空欄はありません。充電器は4.2 V版、SDはDM3AT-SF-PEJM5、LiPoコネクタはPH2・1番BAT+／2番GND。USB4105-GF-A-120も元の型番を選択しました。在庫は発注まで変動します。

JLCPCBプレビューではU1/J1/J3等にモデル原点による可能性のある位置ずれが残り、最終実装位置・全極性の照合は未完了です。基準図、SDアクセス図、KiCad裏面3D図を実装備考へ添付し、実パッドに合わせたJLCPCBエンジニアの修正と確認図を要求しています。アンテナ張り出しはCAD上6.25 mmです。製造ファイル・実装位置の確認を有効にし、自動承認を停止しています。確認図の全パッド・極性・レール干渉を確認してから製造承認してください。

JLCPCBのカートに保存し、決済画面まで準備済みです。商品計は$282.89（PCB $120.47＋実装・部品 $162.42）。見積もり工程の総額は端数処理で$282.88と表示されました。OCS送料$8.79、クーポン−$6.00を適用した決済前の合計は**$285.68**です。決済方法は未確定で、決済手数料は含みません。CPT配送のため輸入時の税・通関手数料は別途、レール除去$2.30と実装備考に基づく追加費用は審査後に請求される可能性があります。支払いは未実施です。

表示納期は基板3日、実装5～6日＋追加オプション1日、OCS輸送4～6営業日です。CAM・実装確認の承認待ち時間は別途です。

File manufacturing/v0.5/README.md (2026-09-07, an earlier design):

# Matrix6 v0.5 — JLCPCB試作発注準備

対象CADはコミット `d1438c606553286f8075416b602664ae09d1bd65`。CAD自体は変更していません。発注・決済は未実施です。

## アップロードするファイル

**[Matrix6-v0.5-Gerber.zip](Matrix6-v0.5-Gerber.zip)** をPCBのアップロード欄で使用します。4銅層、表裏レジスト・シルク・ペースト、外形、PTH/NPTHのExcellon、インピーダンス／穴埋めの指示JPGを含みます。`review/` のファイルを実装用BOM/CPLとしてそのまま提出しないでください。

JLCPCBのGerber解析では4層・40.64 × 61.00 mmと認識されました。これは製造指示JPG追加前の解析確認です。JPGを追加した現行ZIPはログイン後に再アップロード済みで、PCBAのBOM/CPL入力画面まで進みました。ログイン後の製造条件・金額の再確認、詳細なGerber Viewer確認が残っています。注文は未実施です。

## 見積もり条件（仮に基板5枚）

| 項目 | 条件 |
|---|---|
| 外形・枚数 | 40.64 × 61.00 mm、単片、5枚 |
| 層数・板厚 | 4層、呼称1.6 mm |
| 層構成 | JLC04161H-7628 |
| 材料 | FR4 Tg155（0.2 mm穴の選択時にサイトが自動設定） |
| 銅厚 | 外層1 oz、内層0.5 oz |
| 色・表面処理 | 紫・白シルク、ENIG 1 µin |
| インピーダンス | USB差動90 Ω ±10%、L1信号 / L2 GND参照 |
| 最小穴径 | 0.2 mm（U1の熱パッド内に12個） |
| 穴処理 | Epoxy Filled & Capped。熱パッド内のはんだ吸い込みを抑えるために選択 |
| 電気検査 | Flying Probe、サイトが追加した4-Wire Kelvin Test |
| 製造データ確認 | Yes |

2026-09-07の画面見積もりは**基板5枚 US$119.35**。内訳は基板7.00、ENIG16.80、紫5.00、インピーダンス32.84、製造データ確認1.04、穴埋め16.72、最小穴16.72、材料3.34、Kelvin検査16.58、Via Plating Method 3.31 USDです。部品代・実装費・送料・税・クーポンは含みません。ログイン後の実際の注文内容で再計算します。

最初に表示されたUS$62.68は、0.2 mm穴と穴埋め関連条件を反映する前の金額です。最終金額として使用しないでください。

## CAM確認に使う情報

- [製造指示JPG](gerber/Matrix6-fabrication-requirements.jpg)：90 Ωの対象配線、層順、線幅0.28 mm／間隔0.20 mm／表面GND間隔0.50 mm、穴処理。
- PTHは186個。0.2 mm熱パッド穴12、0.3 mmビア130、1.0 mmヘッダー穴40、0.6 mm工具のUSB長穴4。NPTHは0.65 mmが2個。[穴あけレポート](review/drill-report.txt)
- 0.2 mm穴はU1 pad 41の熱ビアです。ヘッダーの1.0 mm穴、USBの長穴、位置決めNPTHは穴埋めしません。CAMに分類と仕上がりを確認します。
- JLCPCB側の材料・エッチング補正による線幅調整と、試験クーポン／測定レポートを製造指示に依頼しています。現在の約91.1 Ωは設計上の2D推定で、製造承認ではありません。
- 「Confirm Production file」は永続的な製造保留を保証する設定ではありません。サイト説明ではUS$300未満の注文は48時間以内に確認しないと自動的に製造へ進む場合があります。

## 部品実装は未リリース

`review/Matrix6-KiCad-BOM-DRAFT.csv` と `review/Matrix6-KiCad-positions.csv` は、保存済みCADから出した**32部品の確認用データ**です。JLCPCB用の部品番号、部品ごとの回転補正、実装対象はまだ確定していません。今回のZIPにBOM/CPLは含めていません。

ログイン後、次のJLCPCB形式ファイルをPCBAの入力欄へアップロードしました。

- [Matrix6-v0.5-BOM.csv](assembly/Matrix6-v0.5-BOM.csv)：22行にまとめた32部品。14品目のJLCPCB番号とメーカー品番を記載。未選定品は仕様を記載し、JLCPCB番号を空欄にして照合対象にしています。
- [Matrix6-v0.5-CPL.csv](assembly/Matrix6-v0.5-CPL.csv)：32行、全てTop、mm、Gerberと同じ絶対原点。H1/H2は1番ピンの座標から部品中心へ24.13 mm補正（Mid Y = −129.13 mm）。角度はKiCadの値を0〜359度に正規化しています。
- [変換検証](assembly/export-validation.json)：CAD・元CSVのハッシュ、32部品の参照番号一致、中心補正、未確定品目を記録。

これらは**部品照合・見積もり用**で、製造承認済みデータではありません。JLCPCB側のモデルとの回転・極性照合、在庫確認、未選定メーカー品番の確定が必要です。再生成は `python3 scripts/export_jlcpcb_assembly.py`。

修正後の照合画面は22品目中21品目に候補、1品目（H1/H2）が未選定となりました。[アップロード結果と残件](assembly/README.md)を参照してください。

初回の自動照合では、C5（指定1µF/16V/X7R）にX5R品が割り当てられました。仕様に合うSamsung CL10B105KO8NNNC / C59782に修正しています。抵抗4種は、0603・1%・100mWのUNI-ROYAL品を指定して在庫不足の自動候補を置き換えました。F1=C25415531、L1=C780206、R11=C844915、SW1/SW2=C231329も設計指定品番との一致を確認して追記しています。

現在のPCBA画面には実装枚数2枚の表示があり、上記の「基板5枚」という仮見積もりとは区別が必要です。最終発注前に基板枚数・実装枚数・納期・配送条件を揃えて確認します。

ESP32-S3-WROOM-1-N8R8はJLCPCBの **C2913201 / Standard Only** を確認しています。閲覧時の在庫4,792、Available Order Qty 4,533で、在庫確保・購入は行っていません。[部品ページ](https://jlcpcb.com/partdetail/3198299-ESP32_S3_WROOM_1N8R8/C2913201)

USB4105-GF-A-120は [C5184243](https://jlcpcb.com/partdetail/GCT-USB4105_GF_A120/C5184243)、SS14-E3/61Tは [C47460](https://jlcpcb.com/partdetail/VishayIntertech-SS14_E361T/C47460)、ST製USBLC6-2SC6は [C7519](https://jlcpcb.com/partdetail/C7519) と品番を照合済みです。これらの発注可能数量はBOM照合画面で再確認します。

残作業：抵抗・コンデンサ・LED・メスソケットのメーカー品番決定、全品のJLCPCB実装在庫確認、C1/C2/C8の実効容量確認、ヘッダーの高さ／実装方法、全32部品の回転・極性照合、総額・納期・配送先の確認。F1/R11など既指定部品の代替品を、未確認のまま自動採用しません。

実装付きならStandard PCBAで進めます。シールド互換性・給電条件・試作での確認事項は [互換性資料](../../docs/matrix5-compatibility.md) を参照してください。

## 再生成

`python3 scripts/export_jlcpcb.py` は、検証済みCADのSHA-256を確認してからCLI出力を生成します。製造指示SVGをJPEGにレンダリングし、`scripts/package_jlcpcb.py` でZIPとハッシュを更新してください。CADを編集した場合は、まずプロジェクトの検証と部品・製造条件の再確認が必要です。

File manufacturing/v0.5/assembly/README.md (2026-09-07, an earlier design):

# JLCPCB BOM / CPL — 部品照合用

2026-09-07、ログイン済みJLCPCBのMatrix6案件に `Matrix6-v0.5-BOM.csv` と `Matrix6-v0.5-CPL.csv` をアップロードし、「Process BOM & CPL」の処理完了を確認しました。

- BOMは22行、32部品。CPLは32行、全てTop。
- H1/H2のCPL座標は部品中心に補正済み。回転はKiCad角度の正規化までで、JLCPCBモデルとの照合は未完了です。
- 初回自動候補のC5はX5Rだったため、指定の1µF/16V/X7Rに合うSamsung CL10B105KO8NNNC（C59782）をBOMに固定して再アップロードしました。
- 自動候補に在庫不足のあった1kΩ/10kΩ抵抗を含め、抵抗4種をUNI-ROYAL 0603 / 1% / 100mW品に固定。修正後の画面では在庫不足表示が解消しました。
- 22品目のうち21品目に候補が付き、H1/H2のメスソケットが未選定です。画面上のconfirmed数は選択・再計算に伴い変動するため、最終数量は各行と配置プレビューで確認します。候補照合は当方の製造承認を意味しません。

## 製造承認までの残件

1. H1/H2のメーカー品番、挿入深さ・高さ、Matrix5シールドとの干渉、実装方法を決定。
2. C1/C2/C8（自動候補CL21A226MAQNNNE / C45783）のDCバイアス・温度・公差込みの実効容量を確認。BOM上のメーカー品番は未固定です。
3. C3/C4/C6/C7、赤/青LEDの自動候補について仕様・極性・寸法を確認し、BOMにメーカー品番を固定。
4. 全部品のJLCPCB配置プレビューとCADパッドを照合し、必要な回転・座標補正をCPLに反映。全実装対象の最終数量確認も必要です。
5. 製造条件、実装枚数（画面上は2枚）、送料込み総額を確認。

注文・支払い・部品在庫の購入は実行していません。Gerberと元CADは変更していません。

再生成は `python3 scripts/export_jlcpcb_assembly.py`。元CAD/CSVのSHA-256、参照番号の一致、ファイルハッシュは `export-validation.json` に記録しています。

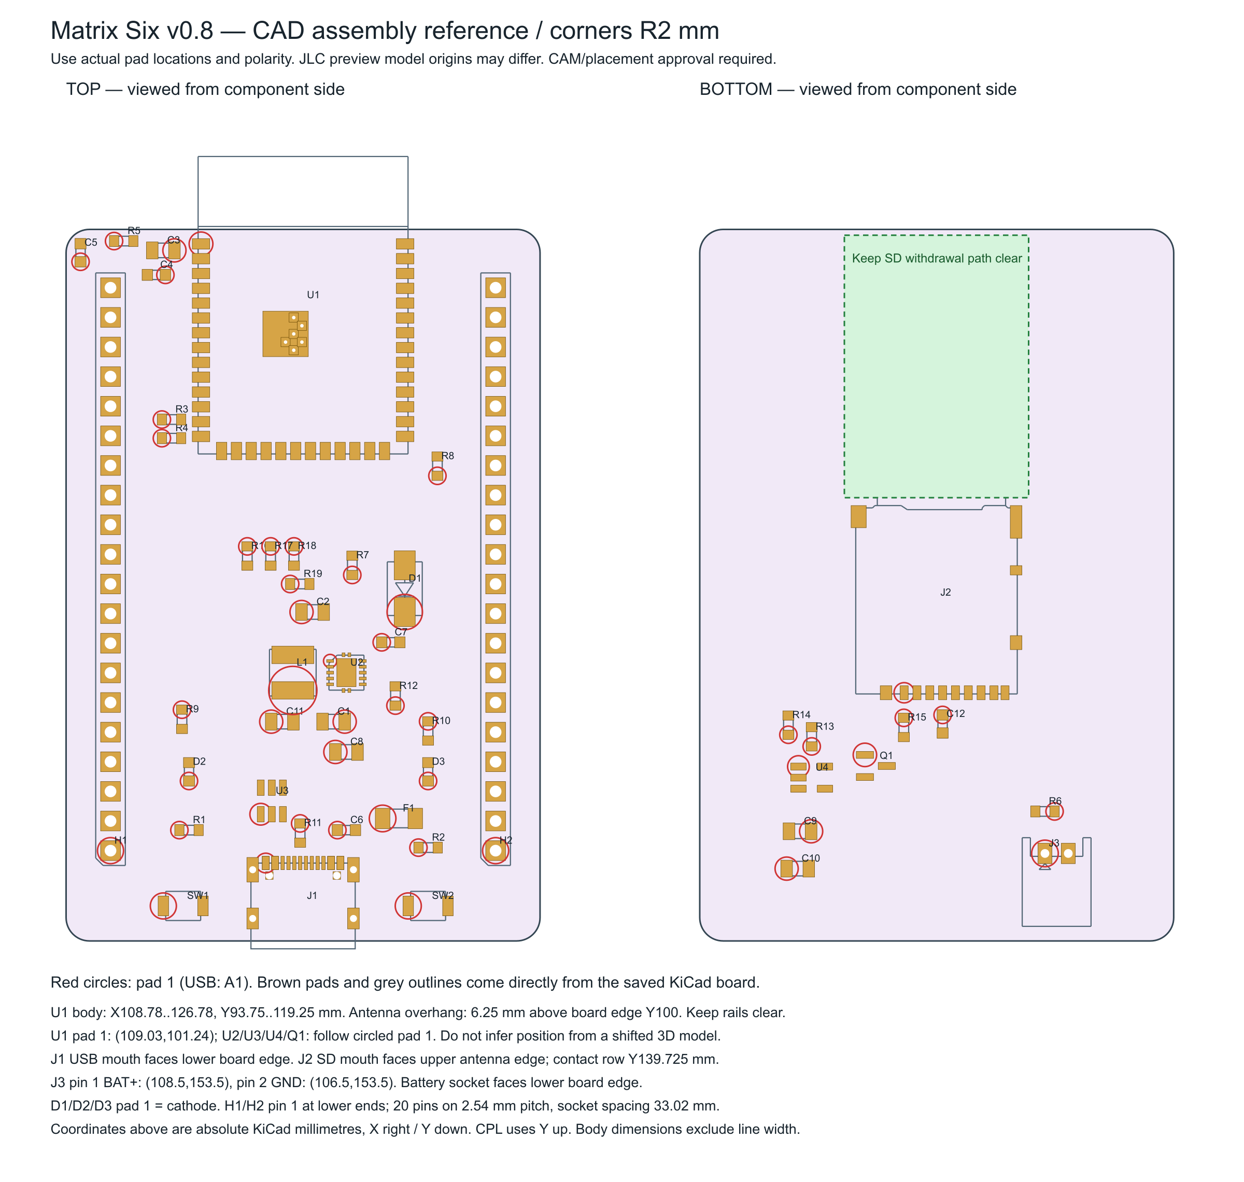
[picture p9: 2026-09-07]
manufacturing/v0.8/review/Matrix6-assembly-reference.png

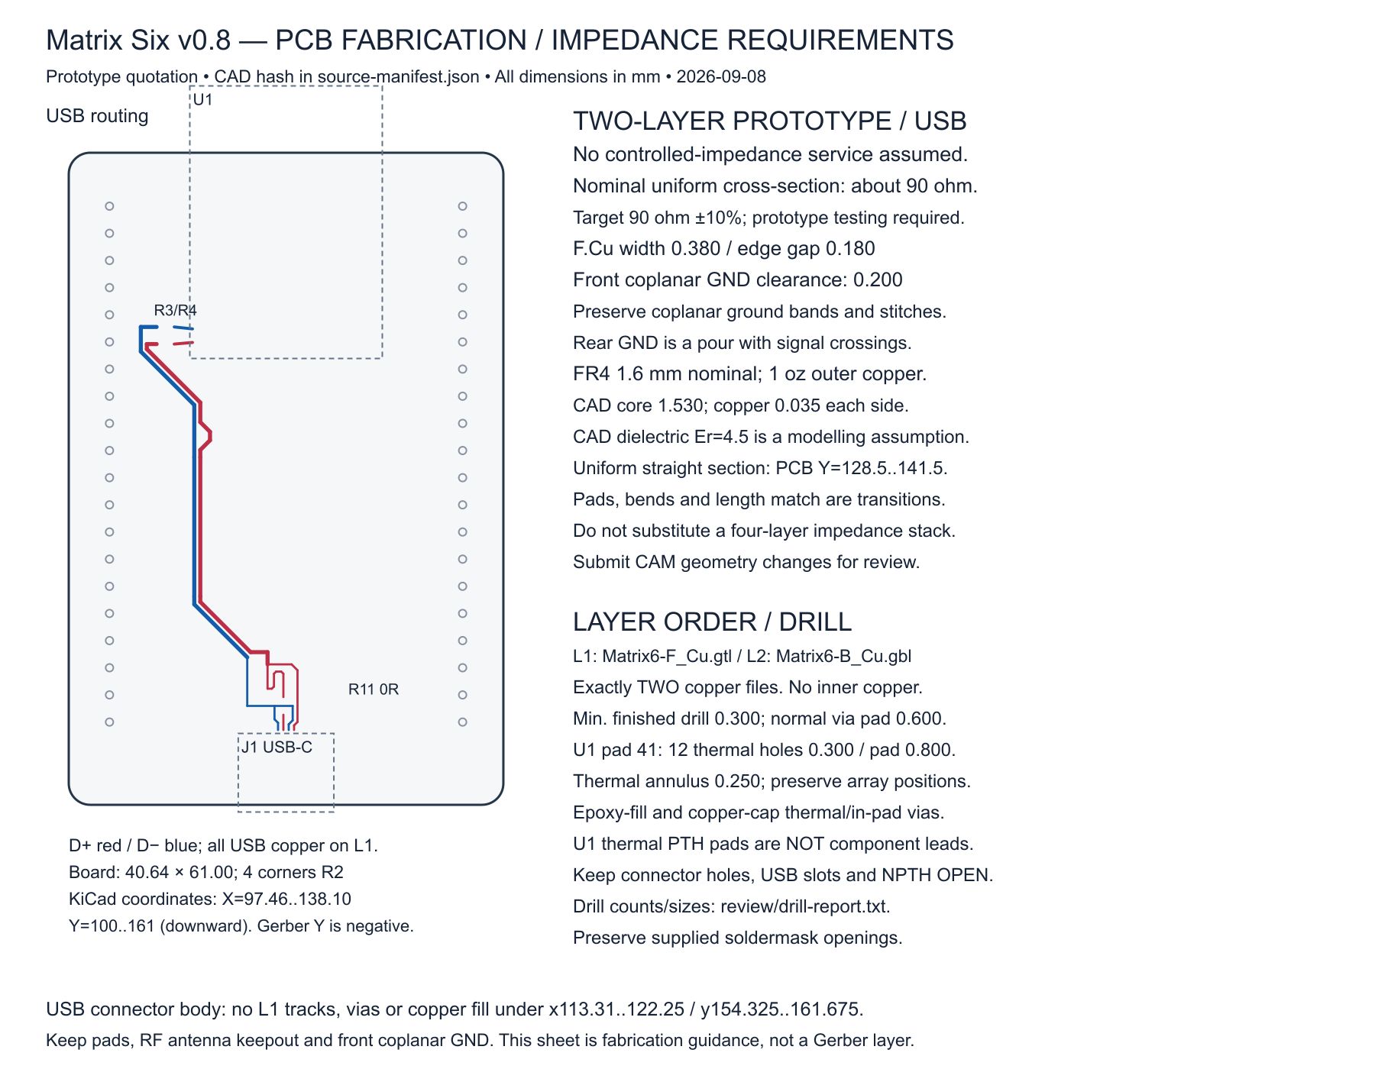
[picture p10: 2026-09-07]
manufacturing/v0.8/gerber/Matrix6-fabrication-requirements.jpg

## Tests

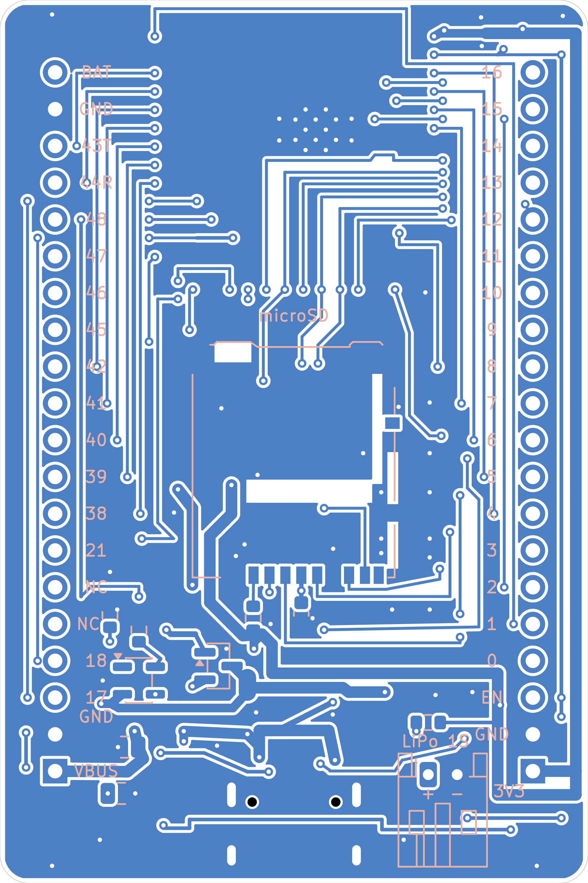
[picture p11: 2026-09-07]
docs/validation/pcb-bottom.png

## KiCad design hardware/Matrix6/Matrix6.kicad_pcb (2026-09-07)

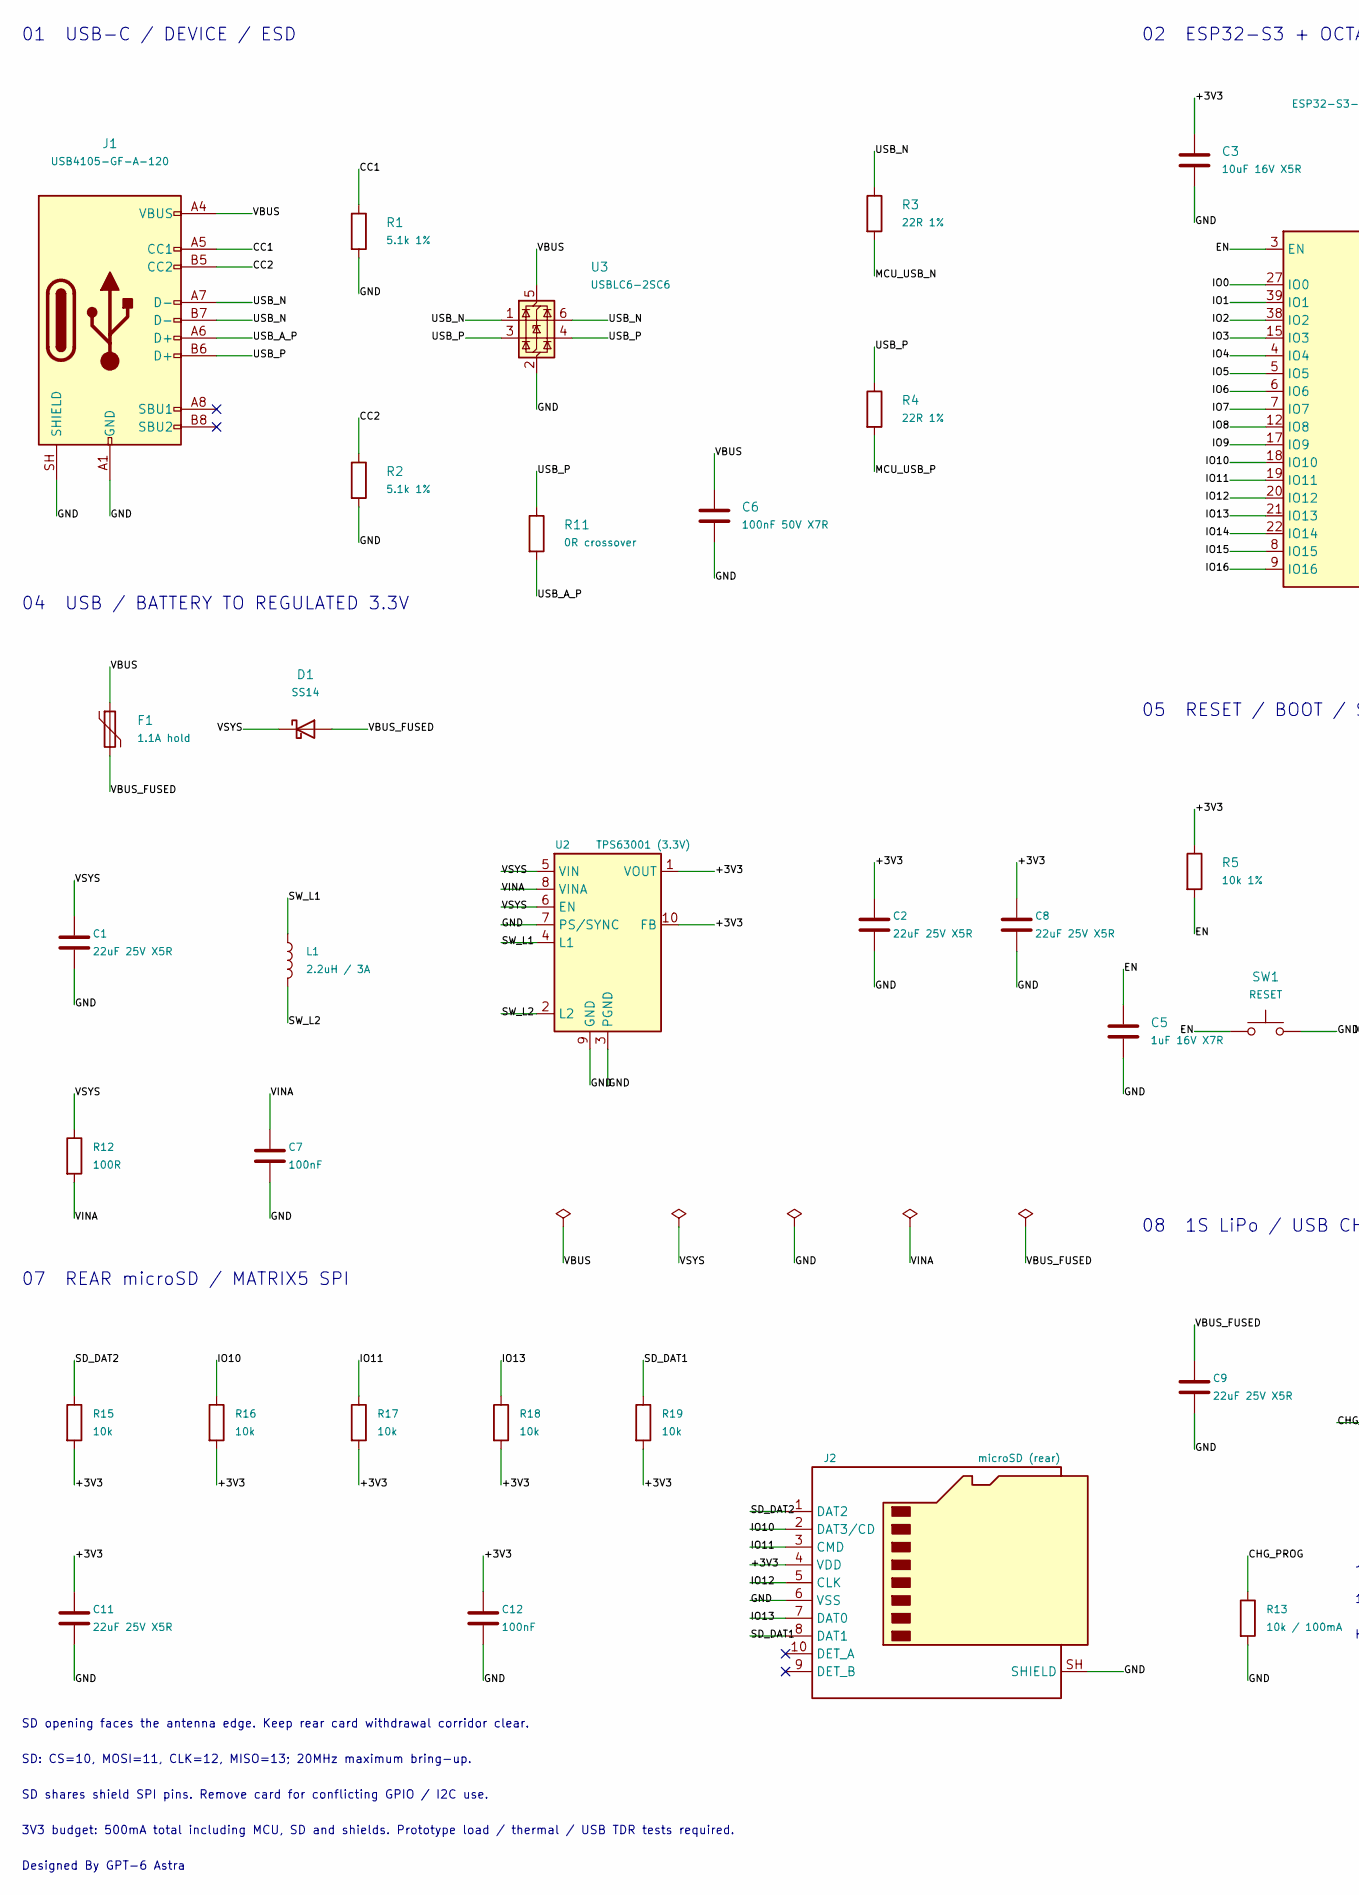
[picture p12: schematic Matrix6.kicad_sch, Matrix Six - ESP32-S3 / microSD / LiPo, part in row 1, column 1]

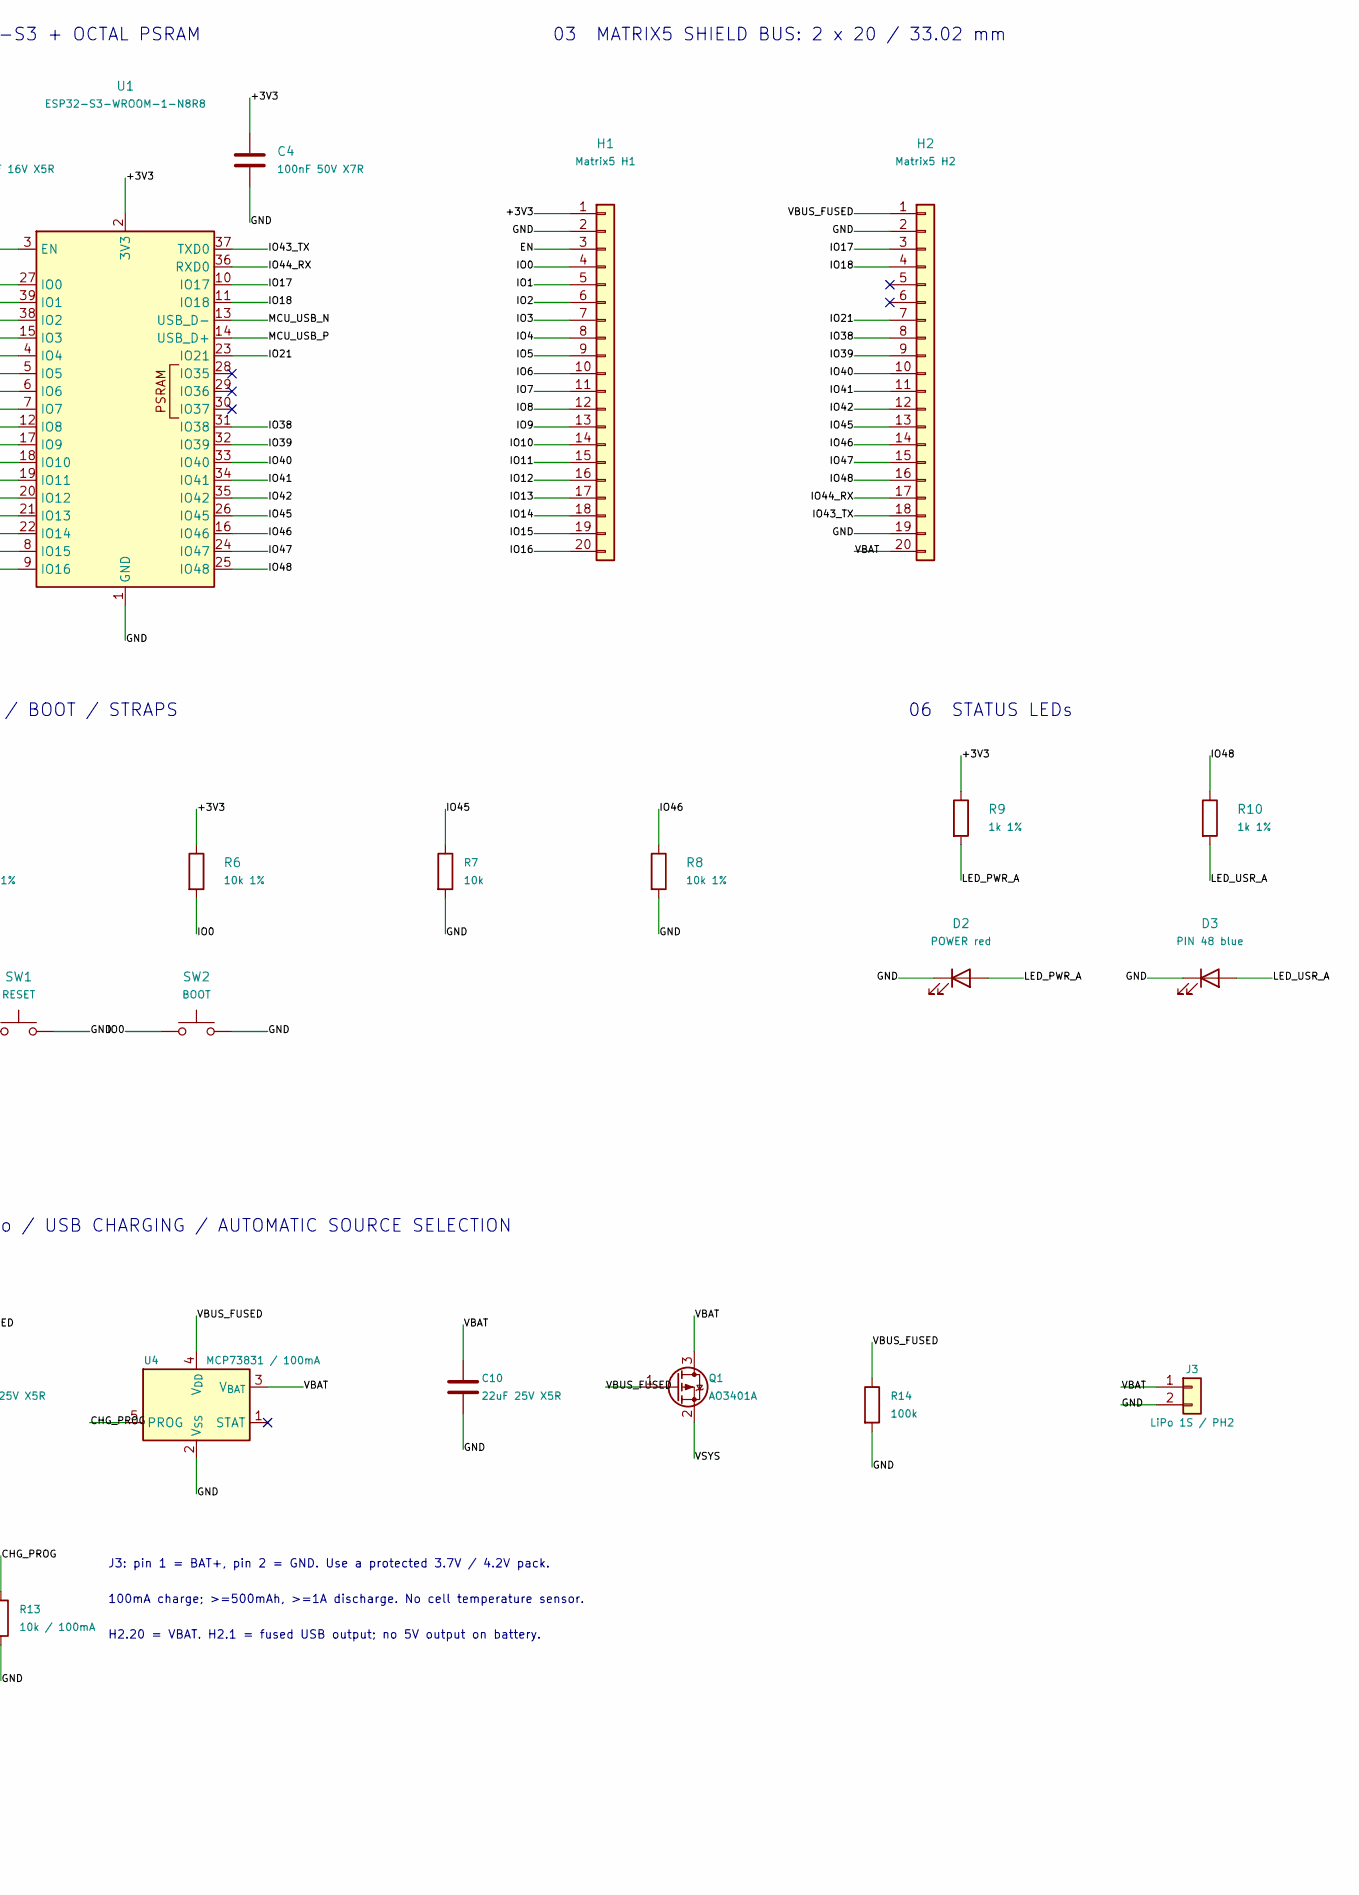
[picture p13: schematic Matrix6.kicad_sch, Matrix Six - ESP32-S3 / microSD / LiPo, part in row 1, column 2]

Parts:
C1, C2, C8, C9, C10, C11: 22uF 25V X5R; C_0805_2012Metric; MPN CL21A226MAQNNNE; LCSC C45783
C3: 10uF 16V X5R; C_0805_2012Metric
C4, C6: 100nF 50V X7R; C_0603_1608Metric
C5: 1uF 16V X7R; C_0603_1608Metric
C7, C12: 100nF; C_0603_1608Metric
D1: SS14; D_SMA; MPN SS14-E3/61T
D2: POWER red; LED_0603_1608Metric
D3: PIN 48 blue; LED_0603_1608Metric
F1: 1.1A hold; Fuse_1206_3216Metric; MPN MF-NSMF110/16X-2
H1: Matrix5 H1; PinSocket_1x20_P2.54mm_Vertical
H2: Matrix5 H2; PinSocket_1x20_P2.54mm_Vertical
J1: USB4105-GF-A-120; USB4105_NoUnderbodyCopper
J2: microSD (rear); microSD_HC_Hirose_DM3AT-SF-PEJM5; MPN DM3AT-SF-PEJM5; LCSC C114218
J3: LiPo 1S / PH2; JST_PH_S2B-PH-K_1x02_P2.00mm_Horizontal; MPN S2B-PH-K-S(LF)(SN); LCSC C173752
L1: 2.2uH / 3A; L_Bourns-SRN4018; MPN SRN4018-2R2M; LCSC C913207
Q1: AO3401A; SOT-23; MPN AO3401A; LCSC C15127
R1, R2: 5.1k 1%; R_0603_1608Metric
R3, R4: 22R 1%; R_0603_1608Metric
R5, R6, R8: 10k 1%; R_0603_1608Metric
R7, R15, R16, R17, R18, R19: 10k; R_0603_1608Metric; MPN 0603WAF1002T5E; LCSC C25804
R9, R10: 1k 1%; R_0603_1608Metric
R11: 0R crossover; R_0603_1608Metric; MPN CRCW06030000Z0EA
R12: 100R; R_0603_1608Metric; MPN 0603WAF1000T5E; LCSC C22775
R13: 10k / 100mA; R_0603_1608Metric; MPN 0603WAF1002T5E; LCSC C25804
R14: 100k; R_0603_1608Metric; MPN 0603WAF1003T5E; LCSC C25803
SW1: RESET; SW_SPST_B3U-1000P
SW2: BOOT; SW_SPST_B3U-1000P
U1: ESP32-S3-WROOM-1-N8R8; ESP32-S3-WROOM-1_Edge
U2: TPS63001 (3.3V); Texas_DRC0010J; MPN TPS63001DRCR; LCSC C28060
U3: USBLC6-2SC6; SOT-23-6
U4: MCP73831 / 100mA; SOT-23-5; MPN MCP73831T-2ACI/OT; LCSC C424093

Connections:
/+3V3: C2.1, C3.1, C4.1, C8.1, C11.1, C12.1, H1.1, J2.4 (VDD), R5.1, R6.1, R9.1, R15.2, R16.2, R17.2, R18.2, R19.2, U1.2 (3V3), U2.1 (VOUT), U2.10 (FB)
/CC1: J1.A5 (CC1), R1.1
/CC2: J1.B5 (CC2), R2.1
/CHG_PROG: R13.1, U4.5 (PROG)
/EN: C5.1, H1.3, R5.2, SW1.1, U1.3 (EN)
/GND: C1.2, C2.2, C3.2, C4.2, C5.2, C6.2, C7.2, C8.2, C9.2, C10.2, C11.2, C12.2, D2.1 (K), D3.1 (K), H1.2, H2.2, H2.19, J1.A1 (GND), J1.A12 (GND), J1.B1 (GND), J1.B12 (GND), J1.SH (SHIELD), J2.6 (VSS), J2.SH (SHIELD), J3.2, R1.2, R2.2, R7.2, R8.2, R13.2, R14.2, SW1.2, SW2.2, U1.1 (GND), U1.40 (GND), U1.41 (GND), U2.3 (PGND), U2.7 (PS/SYNC), U2.9 (GND), U2.11 (PGND), U3.2 (GND), U4.2 (V_{SS})
/IO0: H1.4, R6.2, SW2.1, U1.27 (IO0)
/IO1: H1.5, U1.39 (IO1)
/IO2: H1.6, U1.38 (IO2)
/IO3: H1.7, U1.15 (IO3)
/IO4: H1.8, U1.4 (IO4)
/IO5: H1.9, U1.5 (IO5)
/IO6: H1.10, U1.6 (IO6)
/IO7: H1.11, U1.7 (IO7)
/IO8: H1.12, U1.12 (IO8)
/IO9: H1.13, U1.17 (IO9)
/IO10: H1.14, J2.2 (DAT3/CD), R16.1, U1.18 (IO10)
/IO11: H1.15, J2.3 (CMD), R17.1, U1.19 (IO11)
/IO12: H1.16, J2.5 (CLK), U1.20 (IO12)
/IO13: H1.17, J2.7 (DAT0), R18.1, U1.21 (IO13)
/IO14: H1.18, U1.22 (IO14)
/IO15: H1.19, U1.8 (IO15)
/IO16: H1.20, U1.9 (IO16)
/IO17: H2.3, U1.10 (IO17)
/IO18: H2.4, U1.11 (IO18)
/IO21: H2.7, U1.23 (IO21)
/IO38: H2.8, U1.31 (IO38)
/IO39: H2.9, U1.32 (IO39)
/IO40: H2.10, U1.33 (IO40)
/IO41: H2.11, U1.34 (IO41)
/IO42: H2.12, U1.35 (IO42)
/IO43_TX: H2.18, U1.37 (TXD0)
/IO44_RX: H2.17, U1.36 (RXD0)
/IO45: H2.13, R7.1, U1.26 (IO45)
/IO46: H2.14, R8.1, U1.16 (IO46)
/IO47: H2.15, U1.24 (IO47)
/IO48: H2.16, R10.1, U1.25 (IO48)
/LED_PWR_A: D2.2 (A), R9.2
/LED_USR_A: D3.2 (A), R10.2
/MCU_USB_N: R3.2, U1.13 (USB_D-)
/MCU_USB_P: R4.2, U1.14 (USB_D+)
/SD_DAT1: J2.8 (DAT1), R19.1
/SD_DAT2: J2.1 (DAT2), R15.1
/SW_L1: L1.1, U2.4 (L1)
/SW_L2: L1.2, U2.2 (L2)
/USB_A_P: J1.A6 (D+), R11.2
/USB_N: J1.A7 (D-), J1.B7 (D-), R3.1, U3.1 (I/O1), U3.6 (I/O1)
/USB_P: J1.B6 (D+), R4.1, R11.1, U3.3 (I/O2), U3.4 (I/O2)
/VBAT: C10.1, H2.20, J3.1, Q1.3 (D), U4.3 (V_{BAT})
/VBUS: C6.1, F1.1, J1.A4 (VBUS), J1.A9 (VBUS), J1.B4 (VBUS), J1.B9 (VBUS), U3.5 (VBUS)
/VBUS_FUSED: C9.1, D1.2 (A), F1.2, H2.1, Q1.1 (G), R14.1, U4.4 (V_{DD})
/VINA: C7.1, R12.2, U2.8 (VINA)
/VSYS: C1.1, D1.1 (K), Q1.2 (S), R12.1, U2.5 (VIN), U2.6 (EN)

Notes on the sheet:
01 USB-C / DEVICE / ESD
02 ESP32-S3 + OCTAL PSRAM
03 MATRIX5 SHIELD BUS: 2 x 20 / 33.02 mm
04 USB / BATTERY TO REGULATED 3.3V
05 RESET / BOOT / STRAPS
06 STATUS LEDs
07 REAR microSD / MATRIX5 SPI
08 1S LiPo / USB CHARGING / AUTOMATIC SOURCE SELECTION
J3: pin 1 = BAT+, pin 2 = GND. Use a protected 3.7V / 4.2V pack.
100mA charge; >=500mAh, >=1A discharge. No cell temperature sensor.
H2.20 = VBAT. H2.1 = fused USB output; no 5V output on battery.
SD: CS=10, MOSI=11, CLK=12, MISO=13; 20MHz maximum bring-up.
SD shares shield SPI pins. Remove card for conflicting GPIO / I2C use.
3V3 budget: 500mA total including MCU, SD and shields. Prototype load / thermal / USB TDR tests required.
Designed By GPT-6 Astra
SD opening faces the antenna edge. Keep rear card withdrawal corridor clear.

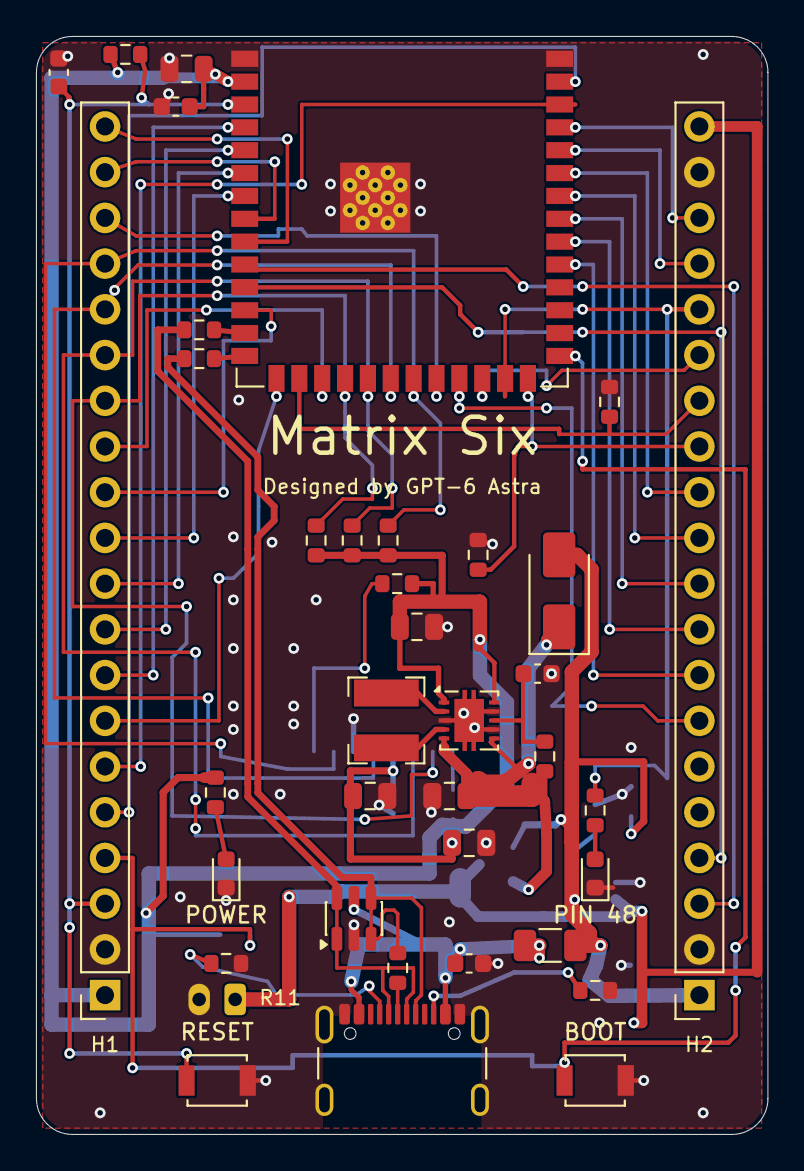
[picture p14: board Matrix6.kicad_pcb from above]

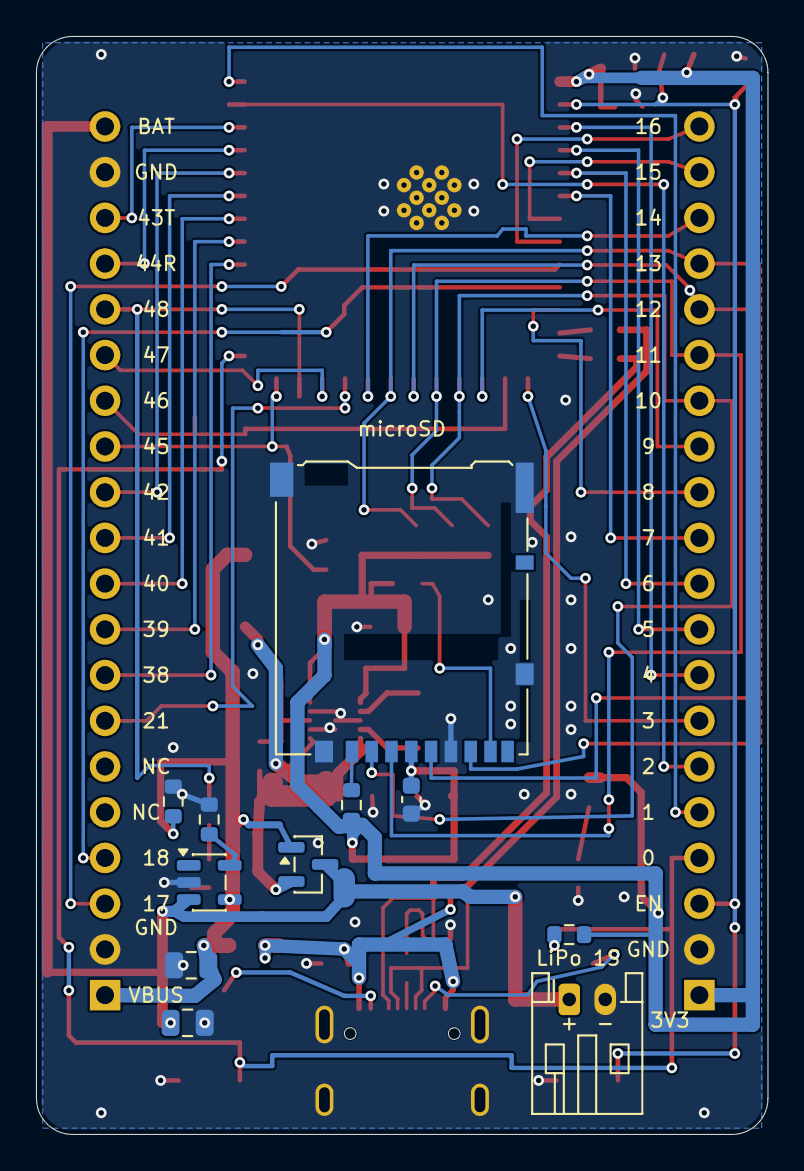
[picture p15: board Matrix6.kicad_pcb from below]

Board: 2 copper layers, 40.6 x 61.0 mm, 48 parts (11 on the bottom side), 53 nets.

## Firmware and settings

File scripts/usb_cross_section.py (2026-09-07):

"""Independent quasi-static 2-D odd-mode finite-difference calculation.

Half of a symmetric differential microstrip: x=0 is the virtual ground.
The conductor is at 1 V, the reference and coplanar grounds at 0 V.
Compute odd-mode C with dielectric and with vacuum; Zdiff=2/(c*sqrt(C*C0)).
This verifies the uniform section only, not connectors, IC packages or bends.
"""
import os
os.environ.setdefault('OPENBLAS_NUM_THREADS','1')
os.environ.setdefault('OMP_NUM_THREADS','1')
from pathlib import Path
import argparse,json,math
import numpy as np
from scipy.sparse import coo_matrix
from scipy.sparse.linalg import spsolve

EPS0=8.8541878128e-12
C0=299792458.0

def axis(anchors,step):
    return np.unique(np.concatenate([np.linspace(a,b,max(2,math.ceil((b-a)/step)+1))
        for a,b in zip(anchors,anchors[1:])]))

def solve(width=.28,gap=.2,height=.2104,copper=.035,er=4.4,mask_er=3.8,
          mask_trace=.0127,mask_base=.02032,coplanar=.5,step=.005,domain=3.,vacuum=False,coplanar_width=None,bottom_reference=True):
    left=gap/2;right=left+width;gnd=right+coplanar
    gx_end=gnd+coplanar_width if coplanar_width is not None else domain
    x=axis(sorted(set([0,left,right,gnd,gx_end,domain])),step)
    y=axis(([0] if bottom_reference else [-3.,0])+[height,height+mask_base,height+copper,height+copper+mask_trace,height+3.0],step)
    X,Y=np.meshgrid(x,y);ny,nx=X.shape
    cu_y=(Y>=height-1e-10)&(Y<=height+copper+1e-10)
    signal=cu_y&(X>=left-1e-10)&(X<=right+1e-10)
    fixed=signal|(cu_y&(X>=gnd-1e-10)&(X<=gx_end+1e-10))
    fixed[[0,-1],:]=True;fixed[:,[0,-1]]=True
    prescribed=np.zeros_like(X);prescribed[signal]=1
    unknown=~fixed;ids=np.full(X.shape,-1,int);ids[unknown]=np.arange(unknown.sum())
    # Permittivity at a face midpoint; account for conformal coating on Cu.
    def eps(xx,yy):
        if vacuum:return np.ones_like(xx+yy)
        dx=np.maximum(np.maximum(left-xx,xx-right),0)
        dy=np.maximum(np.maximum(height-yy,yy-height-copper),0)
        dist=np.hypot(dx,dy)
        dg=np.hypot(np.maximum(np.maximum(gnd-xx,xx-gx_end),0),dy)
        mask=(yy<height+mask_base)|(dist<mask_trace)|(dg<mask_trace)
        return np.where(yy<0,1.,np.where(yy<height-1e-10,er,np.where(mask,mask_er,1.0)))
    # Finite-volume face conductance, midpoint quadrature split at node.
    # Use each adjacent half-face separately so dielectric boundaries at nodes
    # are integrated on both sides rather than arbitrarily classified.
    yh=np.r_[y[0],(y[:-1]+y[1:])/2,y[-1]]
    xh=np.r_[x[0],(x[:-1]+x[1:])/2,x[-1]]
    ex=(x[:-1]+x[1:])[None,:]/2
    gx=(eps(ex,(yh[:-1]+y)[:,None]/2)*(y-yh[:-1])[:,None]
       +eps(ex,(y+yh[1:])[:,None]/2)*(yh[1:]-y)[:,None])/np.diff(x)[None,:]
    ey=(y[:-1]+y[1:])[:,None]/2
    gy=(eps((xh[:-1]+x)[None,:]/2,ey)*(x-xh[:-1])[None,:]
       +eps((x+xh[1:])[None,:]/2,ey)*(xh[1:]-x)[None,:])/np.diff(y)[:,None]
    rows=[];cols=[];data=[];rhs=np.zeros(unknown.sum());diag=np.zeros(unknown.sum())
    def connect(i,j,g,vi,vj):
        for a,b,va,vb in [(i,j,vi,vj),(j,i,vj,vi)]:
            active=a>=0;ai=a[active];bi=b[active];gg=g[active]
            np.add.at(diag,ai,gg)
            free=bi>=0;rows.append(ai[free]);cols.append(bi[free]);data.append(-gg[free])
            np.add.at(rhs,ai[~free],gg[~free]*vb[active][~free])
    connect(ids[:,:-1],ids[:,1:],gx,prescribed[:,:-1],prescribed[:,1:])
    connect(ids[:-1,:],ids[1:,:],gy,prescribed[:-1,:],prescribed[1:,:])
    rows.append(np.arange(len(diag)));cols.append(np.arange(len(diag)));data.append(diag)
    mat=coo_matrix((np.concatenate(data),(np.concatenate(rows),np.concatenate(cols))),shape=(len(diag),len(diag))).tocsr()
    v=prescribed.copy();v[unknown]=spsolve(mat,rhs)
    residual=float(np.linalg.norm(mat@v[unknown]-rhs)/np.linalg.norm(rhs))
    energy2=float(np.sum(gx*np.diff(v,axis=1)**2)+np.sum(gy*np.diff(v,axis=0)**2))
    # Twice the electrostatic energy / V^2 gives capacitance per unit length.
    capacitance=EPS0*energy2
    return capacitance,residual,(x,y,v),int(unknown.sum())

def run(**args):
    c,r,field,n=solve(**args);cv,rv,_,_=solve(**args,vacuum=True)
    return {'parameters_mm':args,'odd_capacitance_F_per_m':c,'vacuum_capacitance_F_per_m':cv,
            'differential_ohm':2/(C0*math.sqrt(c*cv)),'relative_residual':max(r,rv),'unknowns':n},field

if __name__=='__main__':
    ap=argparse.ArgumentParser();ap.add_argument('--width',type=float,default=.28)
    ap.add_argument('--step',type=float,default=.005);ap.add_argument('--er',type=float,default=4.4)
    ap.add_argument('--height',type=float,default=.2104);ap.add_argument('--output',default='/tmp/usb-section.json')
    ap.add_argument('--plot');a=ap.parse_args()
    result,field=run(width=a.width,step=a.step,er=a.er,height=a.height)
    Path(a.output).write_text(json.dumps(result,indent=2));print(json.dumps(result),flush=True)
    if a.plot:
        import matplotlib;matplotlib.use('Agg')
        import matplotlib.pyplot as plt
        x,y,v=field;fig,ax=plt.subplots(figsize=(9,3.5),layout='constrained')
        xx=np.r_[-x[:0:-1],x];vv=np.c_[-v[:,:0:-1],v]
        im=ax.contourf(xx,y,vv,31,cmap='RdBu_r',vmin=-1,vmax=1)
        ax.set(xlim=(-1.2,1.2),ylim=(0,.6),xlabel='Across pair (mm)',ylabel='Above L2 GND (mm)',
               title=f'USB uniform section — {result["differential_ohm"]:.1f} Ω differential (2-D estimate)')
        fig.colorbar(im,ax=ax,label='Odd-mode potential (V)');fig.savefig(a.plot,dpi=180)

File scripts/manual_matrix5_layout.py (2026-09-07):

"""Migrate the v0.4 snapshot using explicitly specified routes, without autorouting.

KiCad Python with pcbnew + wx is required. Rebuilds from the first git commit;
overwrites the working Matrix6 PCB and schematic. Save GUI edits before use.
"""
from pathlib import Path
import copy, json, math, os, subprocess, tempfile, uuid
from sexpr import *

ROOT = Path(__file__).resolve().parent.parent
OUT = ROOT / 'hardware/Matrix6'
BASE_REV = 'ee580b181c5c248c455f0519c6c52200018bf0b3'
def original(ext):
    return subprocess.check_output(['git', 'show', f'{BASE_REV}:hardware/Matrix6/Matrix6.{ext}'], cwd=ROOT).decode()

H1 = ['+3V3','GND','EN','IO0'] + [f'IO{i}' for i in range(1,17)]
H2 = ['VBUS_FUSED','GND','IO17','IO18',None,None,'IO21','IO38','IO39','IO40','IO41','IO42','IO45','IO46','IO47','IO48','IO44_RX','IO43_TX','GND',None]
MAP = {'H1': H1, 'H2': H2}
sch = parse(original('kicad_sch'))
rootid = child(sch,'uuid')[1]
def uid(key): return str(uuid.uuid5(uuid.UUID(rootid), 'matrix6-v05-'+key))
def prop(s,k): return next(x for x in children(s,'property') if x[1]==k)
symbols = {prop(s,'Reference')[2]:s for s in children(sch,'symbol')}
for old,new in [('J2','H1'),('J3','H2')]:
    s = symbols[old]
    lib = next(x for x in children(child(sch,'lib_symbols'),'symbol') if x[1]==child(s,'lib_id')[1])
    sx,sy = map(float,child(s,'at')[1:3])
    for pin in [p for g in children(lib,'symbol') for p in children(g,'pin')]:
        n = int(child(pin,'number')[1]); px,py=map(float,child(pin,'at')[1:3]); point=(sx+px,sy-py)
        wire=next(w for w in children(sch,'wire') if any(math.dist(tuple(map(float,q[1:3])),point)<1e-4 for q in children(child(w,'pts'),'xy')))
        ends=[tuple(map(float,q[1:3])) for q in children(child(wire,'pts'),'xy')]
        label=next(l for l in children(sch,'label') if any(math.dist(tuple(map(float,child(l,'at')[1:3])),q)<1e-4 for q in ends))
        name=MAP[new][n-1]
        if name is None:
            sch.remove(wire); sch.remove(label)
            sch.append(parse(f'(no_connect (at {point[0]} {point[1]}) (uuid "{uid(new+str(n)+"nc")}"))'))
        else: label[1]=name
    prop(s,'Reference')[2]=new
    prop(s,'Value')[2]='Matrix5 '+new
    prop(s,'Footprint')[2]='Connector_PinSocket_2.54mm:PinSocket_1x20_P2.54mm_Vertical'
    inst=child(child(child(s,'instances'),'project'),'path'); child(inst,'reference')[1]=new
for s in children(sch,'symbol'):
    inst=child(s,'instances')
    if inst:
        for pr in children(inst,'project'):pr[1]='Matrix6'
child(child(sch,'title_block'),'title')[1]='Matrix6 - ESP32-S3 / Matrix5 shield interface'
child(child(sch,'title_block'),'rev')[1]='0.5'
for t in children(sch,'text'):
    t[1]={'03  2 x 20 GPIO HEADERS': '03  MATRIX5 SHIELD BUS: 2 x 20 / 33.02 mm', 'GPIO19/20: dedicated native USB D-/D+; no header stubs.': 'H2.5 / H2.6 / H2.20: NC (USB D-/D+ and VBAT are not exposed).', '3V3 header pins are OUTPUT ONLY. Use USB-C or regulated +5V header input.': 'H1.1 = 3V3 OUTPUT; H2.1 = fused USB VBUS OUTPUT. Power the board via USB-C.', '+5V header and USB may coexist: D1 blocks current back into USB VBUS.': 'Do not drive H2.1 from another supply: the fuse does not block backfeed into USB.', '3V3 budget: 500 mA total continuous, ambient 50 C. Verify prototype thermals and USB TDR.': '50 C budget: 3V3 500 mA total incl. MCU + VBUS shield 100 mA. Verify prototype thermals / USB TDR.'}.get(t[1],t[1])
(OUT/'Matrix6.kicad_sch').write_text(dump(sch))

import pcbnew as p, wx
app=wx.App(False)
tmp=Path(tempfile.mkdtemp(prefix='matrix6-source-'))/'baseline.kicad_pcb';tmp.write_text(original('kicad_pcb'));tmp.with_suffix('.kicad_pro').write_text(original('kicad_pro'));tmp.with_suffix('.kicad_dru').write_text(original('kicad_dru'))
b=p.LoadBoard(str(tmp)); b.SetFileName(str(OUT/'Matrix6.kicad_pcb'))
mm=p.FromMM
def pt(x,y=None):
    if y is None:x,y=x
    return p.VECTOR2I(mm(x),mm(y))
def xy(v):return tuple(round(p.ToMM(q),6) for q in (v.x,v.y))
fps={f.GetReference():f for f in b.GetFootprints()}; removed=[]
def drop(t):removed.append(t);b.Remove(t)
nets={str(k):v for k,v in b.GetNetInfo().NetsByName().items()}
def net(name):
    n=name if name.startswith('unconnected-') else '/'+name
    if n not in nets:nets[n]=p.NETINFO_ITEM(b,n);b.Add(nets[n])
    return nets[n]
def pad(ref,n):return xy(next(q for q in fps[ref].Pads() if q.GetNumber()==str(n)).GetPosition())
def path(name,points,layer=p.B_Cu,width=.20):
    for a,c in zip(points,points[1:]):
        if a==c:continue
        t=p.PCB_TRACK(b);t.SetStart(pt(a));t.SetEnd(pt(c));t.SetWidth(mm(width));t.SetLayer(layer);t.SetNet(net(name));b.Add(t)
def via(name,at,size=.6,drill=.3):
    v=p.PCB_VIA(b);v.SetPosition(pt(at));v.SetWidth(mm(size));v.SetDrill(mm(drill));v.SetLayerPair(p.F_Cu,p.B_Cu);v.SetNet(net(name));b.Add(v)
LIB=Path(os.environ.get('KICAD_FOOTPRINT_DIR','/Applications/KiCad/KiCad.app/Contents/SharedSupport/footprints'))
for old,new,x in [('J2','H1',101.27),('J3','H2',134.29)]:
    f0=fps[old];f=p.FootprintLoad(str(LIB/'Connector_PinSocket_2.54mm.pretty'),'PinSocket_1x20_P2.54mm_Vertical');b.Add(f)
    f.SetReference(new);f.SetValue('Matrix5 '+new);f.SetFPID(p.LIB_ID('Connector_PinSocket_2.54mm','PinSocket_1x20_P2.54mm_Vertical'))
    f.SetPath(f0.GetPath());f.SetPosition(pt(x,153.26));f.SetOrientationDegrees(180)
    for q in f.Pads():
        n=int(q.GetNumber());name=MAP[new][n-1]
        q.SetNet(net(name if name else f'unconnected-({new}-Pin_{n}-Pad{n})'));q.SetPinType('passive' if name else 'no_connect')
    f.Value().SetVisible(False);f.Reference().SetVisible(True);f.Reference().SetPosition(pt(x,156.0));f.Reference().SetTextAngle(p.EDA_ANGLE(0,p.DEGREES_T));f.Reference().SetTextSize(pt(.8,.8));f.Reference().SetTextThickness(mm(.12))
    drop(f0);del fps[old];fps[new]=f

# Remove old GPIO routing, keeping the short module pad escapes and EN RC network.
fanouts={}
for t in list(b.GetTracks()):
    name=t.GetNetname();a,c=xy(t.GetStart()),xy(t.GetEnd())
    if name.startswith('/IO') or name=='/EN':
        if not isinstance(t,p.PCB_VIA) and t.GetLayer()==p.F_Cu:
            if name=='/EN':continue
            if (a[0] in [109.03,126.53] and a[1]<119) or (a[1]==119 and c[1]==120):
                fanouts[name[1:]]=c;continue
            if name=='/IO0' and a in [(122.325,123),(126.8,158)]:continue
        if isinstance(t,p.PCB_VIA) and (a in [(108.1,103.78),(105.8,156.5),(121.9,123.8),(126.8,157)]):continue
        drop(t)

# Remove obsolete header power branches; the regulator and USB remain in place.
for t in list(b.GetTracks()):
    if isinstance(t,p.PCB_VIA):continue
    n=t.GetNetname();a,c=xy(t.GetStart()),xy(t.GetEnd());la=t.GetLayer()
    if n=='/+3V3' and la==p.B_Cu:
        if a in [(104.5,102.3),(108.1,102.51),(107.7,102.3),(102.54,104.26),(100.8,105),(100.8,146.3),(101.4,146.9),(103.7,146.9),(120.58,148.18)] or c in [(133.02,148.18),(120.58,148.18)]:drop(t)
    if n=='/+5V' and la==p.In2_Cu and (max(a[0],c[0])>129 or min(a[0],c[0])<=114.2):drop(t)
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

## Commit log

2026-09-07 Import manually routed ESP32-S3 DevBoard v0.4 KiCad design
    [Matrix6.kicad_pcb, Matrix6.kicad_sch]
2026-09-07 Align Matrix6 v0.5 headers and manual routing with Matrix5 shields
    Use two 20-pin sockets at 33.02 mm spacing and remap the GPIO and power nets against Matrix5 Main and all eleven shield designs. Document the three unused USB/VBAT pins, fused VBUS output and prototy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
    Preserve the reviewed USB copper, connector body keepout, continuous L2 GND and design rules. Include schematic/PCB/3D previews and reproducible DRC, ERC, pin-map, keepout and electrical checks; all 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
    [Matrix6.kicad_pcb, Matrix6.kicad_sch]
2026-09-07 Prepare Matrix6 v0.5 JLCPCB prototype fabrication package
    Export the verified four-layer CAD to Gerber and separate PTH/NPTH drills. Include 90-ohm USB and thermal-via fill/cap fabrication guidance, hashes, and the provisional five-board quote conditions.
    Keep raw 32-part KiCad BOM and positions explicitly marked as review-only. PCBA part selection, stock, rotations and account/order confirmation remain open; no order or payment was submitted.
    [Matrix6-B_Cu.gbl, Matrix6-B_Mask.gbs, Matrix6-B_Paste.gbp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]
2026-09-07 Prepare and upload JLCPCB BOM and CPL for component matching
    [Matrix6-v0.5-BOM.csv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]
2026-09-07 Clarify live BOM matching counts and remaining placement review
2026-09-07 Add rear microSD with clear extraction path and LiPo power to Matrix Six
    [Matrix6-B_Cu.gbl, Matrix6-B_Mask.gbs, Matrix6-B_Paste.gbp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]
2026-09-07 Prepare Matrix Six v0.6 JLCPCB assembly quote and placement reference
    [Matrix6-v0.6-BOM.csv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]
2026-09-07 Round Matrix Six corners to R2 and prepare v0.7 manufacturing files
    [Matrix6-B_Cu.gbl, Matrix6-B_Mask.gbs, Matrix6-B_Paste.gbp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]
2026-09-07 Evaluate two-layer feasibility and correct manufacturing cost assumptions
    [review_two_layer_feasibility.py]
2026-09-07 Redesign Matrix Six v0.8 for two copper layers
    Manually reroute signal and power nets, match the top-only USB pair with coplanar ground, and enlarge thermal drills to 0.3 mm. Preserve Matrix5 shield mapping, R2 outline, rear SD access and LiPo functions. Enlarge the front Matrix Six title and place its design credit beneath it. Include DRC/ERC, geometry and electrical screening, 30-degree renders, manufacturing files and a JLCPCB cost comparison.
    [Matrix6-B_Cu.gbl, Matrix6-B_Mask.gbs, Matrix6-B_Paste.gbp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]
2026-09-07 Center front branding and move R8 beside the module
    Align both silkscreen lines to the board centre and move the IO46 pull-down to clear the title area. Reroute its branch explicitly, refill ground and regenerate manufacturing data, CPL and 3D preview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
    [Matrix6-B_Cu.gbl, Matrix6-B_Mask.gbs, Matrix6-B_Paste.gbp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]
